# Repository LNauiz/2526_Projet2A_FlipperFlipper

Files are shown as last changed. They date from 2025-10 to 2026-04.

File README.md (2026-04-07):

# 2526_Projet2A_Flipper
Notre objectif est de réaliser un Flipper (ou billard électrique). Notre flipper aurait tous les éléments suivants : les batteurs, les bumpers, un lanceur, un compteur de point et des éclairages (réalisés avec des néopixels), tels que montré sur les dessins suivants : 

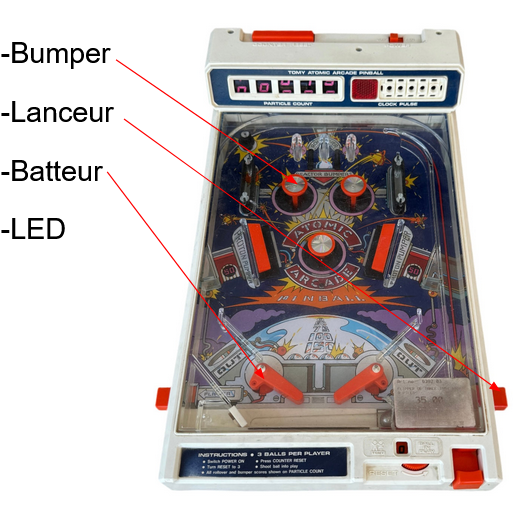
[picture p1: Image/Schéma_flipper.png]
Schéma flipper
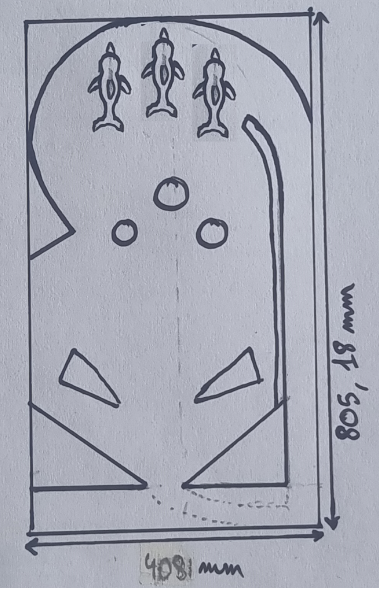
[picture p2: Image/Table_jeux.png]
dessin
 

Afin de marquer des points, le joueur doit soit passer entre les dauphins soit tapper contre les pièces triangulaires ou contre les bumpers.
### Matériel
* Solénoïdes*4 : Heschen Electroaimant solénoïde, HS-1546B, DC24V, 1.5A, course 20 mm, type Push Pull

* Néopixels alimentées à 5 V

* Photodiodes*3

* Détails de la PCB seront donnés dans la partie concernée

### Logiciels utilisés
KiCAD (design PCB), STM32CubeIDE (Software), Onshape (Modélisation 3D)

## Les Bumpers
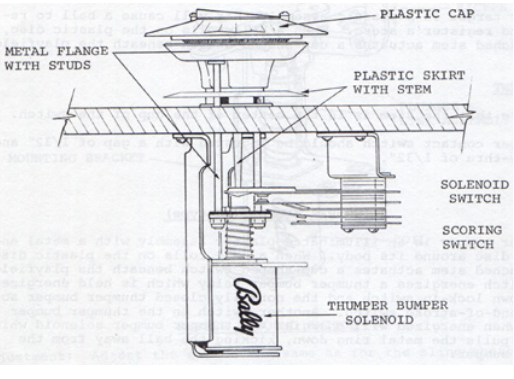
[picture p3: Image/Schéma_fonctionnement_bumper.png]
Schéma fonctionnement bumper


Le fonctionnement du bumper est le suivant : lorsque la balle arrive contre le bumper, elle boucle un circuit entre un anneau proche du circuit ainsi que le cylindre central ce qui va provoquer l'abattement d'une collerette (nommée "metal flange with studs" sur le schéma) repoussant ainsi la balle.
Pour réaliser cet "abattement" on utilise des **solénoïdes** que nous commençons par tester : 
### _Premier test solénoïde_

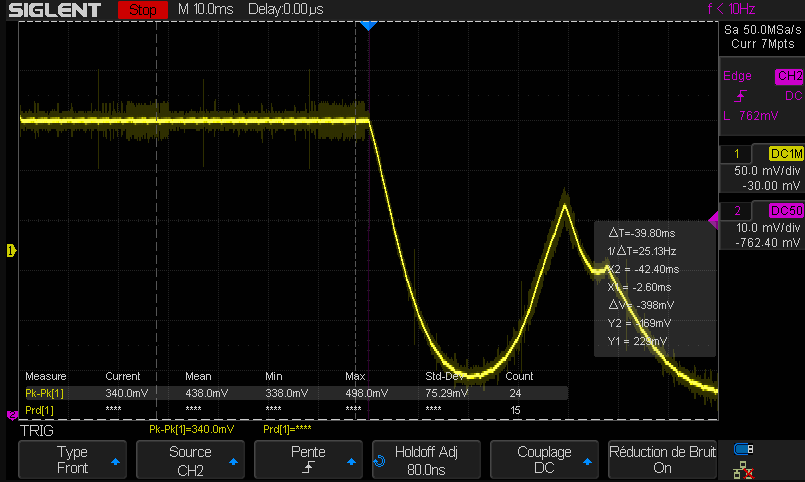
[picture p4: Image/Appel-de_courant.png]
premier test solénoïde


Afin d'utiliser ces solénoïdes pour réaliser des bumpers nous avons besoin d'un support (que nous avons dessiné sur Onshape) :

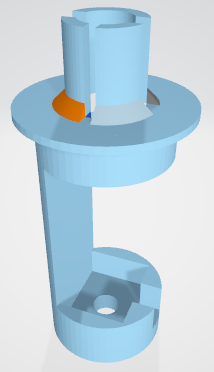
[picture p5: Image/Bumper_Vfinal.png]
Support bumper imprimé


Pour relier la colerette au solénoïde, on utilise des tiges filetés et des écrous nylstop ainsi qu'une pièce imprimé en 3d calée dans le solénoïde.

Afin de détecter si la balle a touché le bumper, nous avons entouré la base et le mât du bumper de scotch cuivré. La balle, en contact avec les deux morceaux de scotch, ferme le cicuit connecté à un GPIO pin de la STM, ce qui permet de commander le solénoïde du bumper.

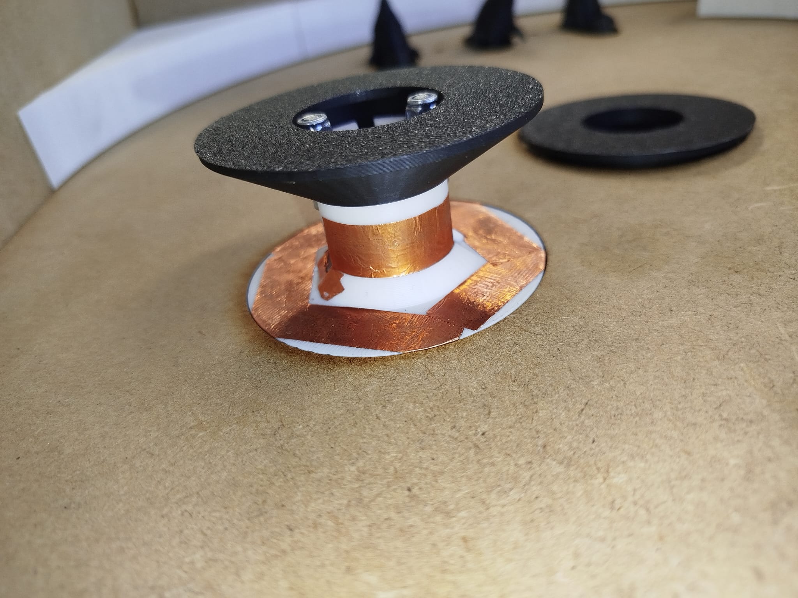
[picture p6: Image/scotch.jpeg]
Scotch

Bottom
## Les Batteurs
Les batteurs sont au nombre de 2 et seront contrôlés par des boutons poussoirs qui activeront d'autres solénoïdes. Ainsi nous avons du réaliser un dispositif afin de pouvoir tranformer la translation produite par le solénoïde en rotation de 60° pour les batteurs. Par Onshape, on modélise les pièces suivantes : 

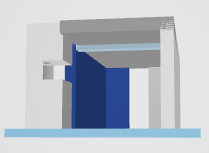
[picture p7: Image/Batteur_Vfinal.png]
Batteur total
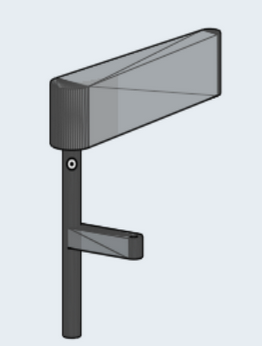
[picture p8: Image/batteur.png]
batteur uniquement
 

Il est nécessaire d'ajouter des écrous nylstops à l'intérieur des pièces pour ne pas que ces derniers se dévissent.\
Malgré cela, on a remarqué que les écrous nylstops avaient une certaine marge de mouvement, ce qui désaxe les batteurs au fil du temps.

## Le Lanceur
La première idée afin de réaliser le lanceur est de réaliser un Coilgun dont le principe est le suivant : 
Nous prenons une balle de 25mm de diamètre que nous voulons faire aller à **6 m/s** lors du lancement ainsi le dimmensionnement de notre Coilgun serait le suivant : 
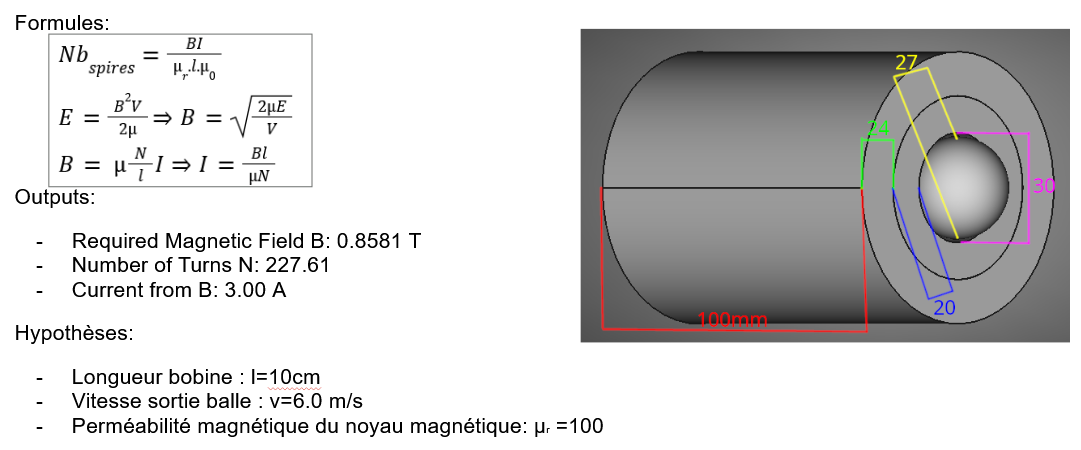
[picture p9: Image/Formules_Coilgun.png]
Calculs Coilgun


Nous avons fini par nous rabattre sur un simple ressort monté sur une tige filetée.

## Les boutons

Après plusieurs tests, nous avons remarqué que les boutons qui étaient, d'après la datasheet, pour du 5V fonctionnaient en 24V. Afin d'avoir un prototype "fonctionnel", nous avons donc simplement branché les batteurs de cette manière: 24V --- Bouton --- Batteur.\
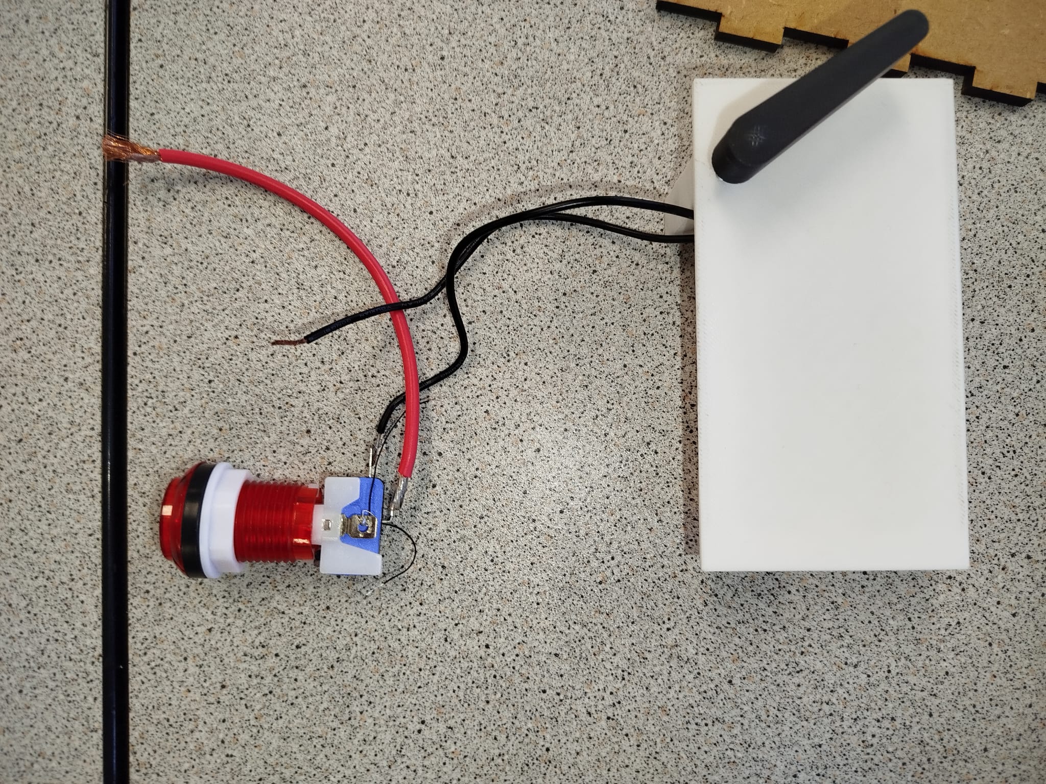
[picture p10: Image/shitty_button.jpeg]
Button


## Le Compteur
Afin d'afficher le score réalisé par le joueur nous devons réaliser un compteur, on utilisera un afficheur 7 segments.\
Pour ce faire nous utiliserons des Néopixels, le code serait réalisé en langage C.\
Voici le support (réalisé sur Onshape) sur lequel nous voulons coller et souder les néopixels : 

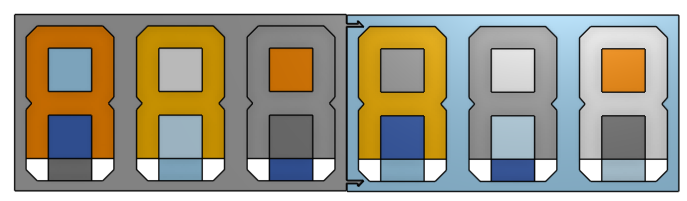
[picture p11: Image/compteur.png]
compteur_imprimé
 

Afin de dissiper la lumière pour ne pas être ébloui par les LED, on peut mettre un difuseur lumineux qui se compose de 1 à 2 couches de PLA.\
Nous avons remarqué que chaque LED doit être séparé par un mur afin de ne pas éclairer les parties des autres (par exemple: le 1 ressemble au 3 sans mur).

## Les Photodiodes
Afin de détecter lorsque la balle passe entre les obstacles ou lorsqu'elle heurte l'obstacle triangulaire du milieu de la table, nous utilisons des photodiodes.
Les premiers tests avec un PCB fait par Monsieur Papazoglou ont été laborieux, on remarque que pour vérifier que ces photodiodes sont bien fonctionnelles nous pouvons lorsqu'elles sont branchées utiliser l'appareil photo de notre téléphone, lorsqu'une lumière violette (le laser) émane de la photodiode, cette dernière est fonctionnelle, si ce n'est pas le cas cela signifie que la photodiode a subi une dégradation irréversible (sûrement du à une alimentation excessive).

## Le PCB
Afin de commander les solénoïdes nous avons réalisé (sur KiCAD) et soudé un premier PCB que voici : 
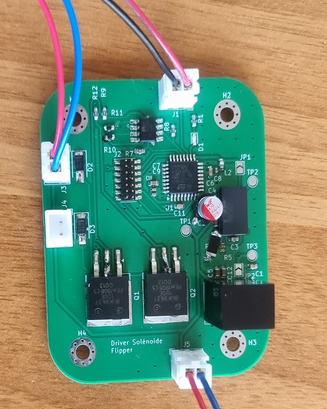
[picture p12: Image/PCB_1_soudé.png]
PCB 1


Lors des soudures nous avons rencontré plusieurs problèmes tels que des empreintes erronées (une résistance R et un condensateur sous-estimés en taille et une patte manquante sur les MOSFETs)
Lors des tests, le Buck de ce premier PCB est fortement monté en température. Nous sommes donc passé au montage suivant (PCB corrigé par Monsieur Papazoglou) :

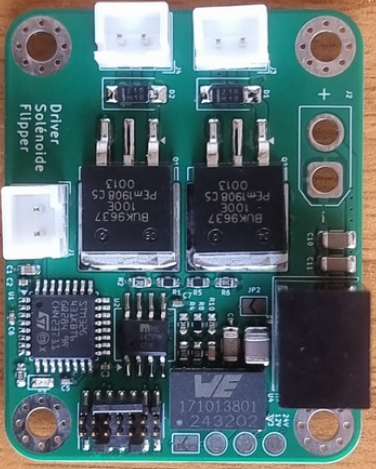
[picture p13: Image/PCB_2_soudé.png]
PCB 2


Lors des test, le Buck de ce PCB est également monté en température. Nous pensons que le problème viendrait d'un court-circuit créé lors de la soudure Pour poursuivre notre projet nous pensons donc changer le buck qui nous cause problème quel que soit le montage par le même type de régulateur à 3 pin que ce celui qui transforme le 24V en 12V. Nous avons construit le PCB avec la possibilité de séparer la partie puissance et la partie commande. Nous avons donc prévu de tester cette dernière lors des prochaines semaines et de commencer à concevoir le PCB final qui commandera l'ensemble du système.

Le PCB final a été réalisé
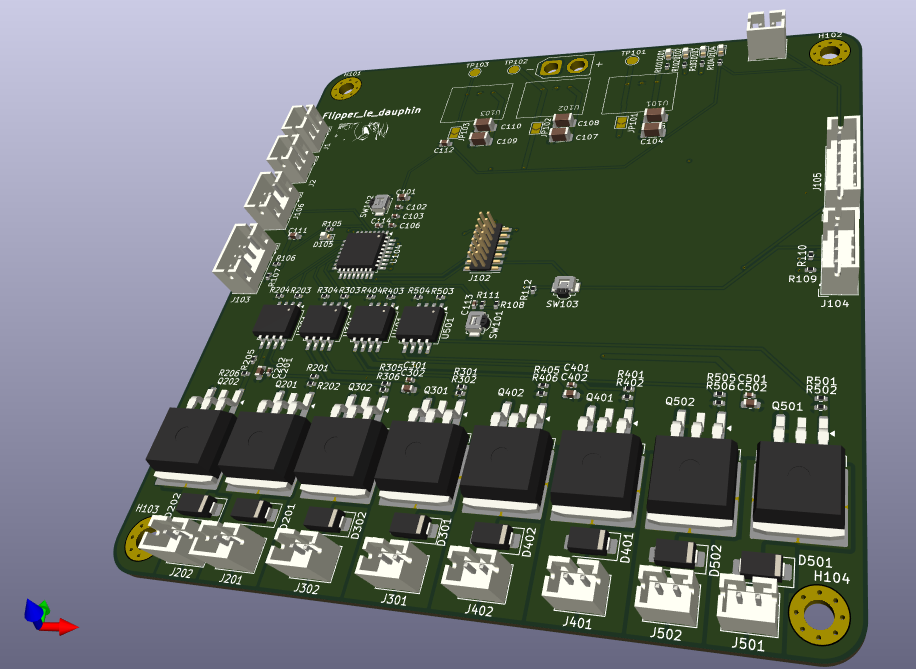
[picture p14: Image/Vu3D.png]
PCB 3


## Software

Voici le schéma fonctionnel de notre système.
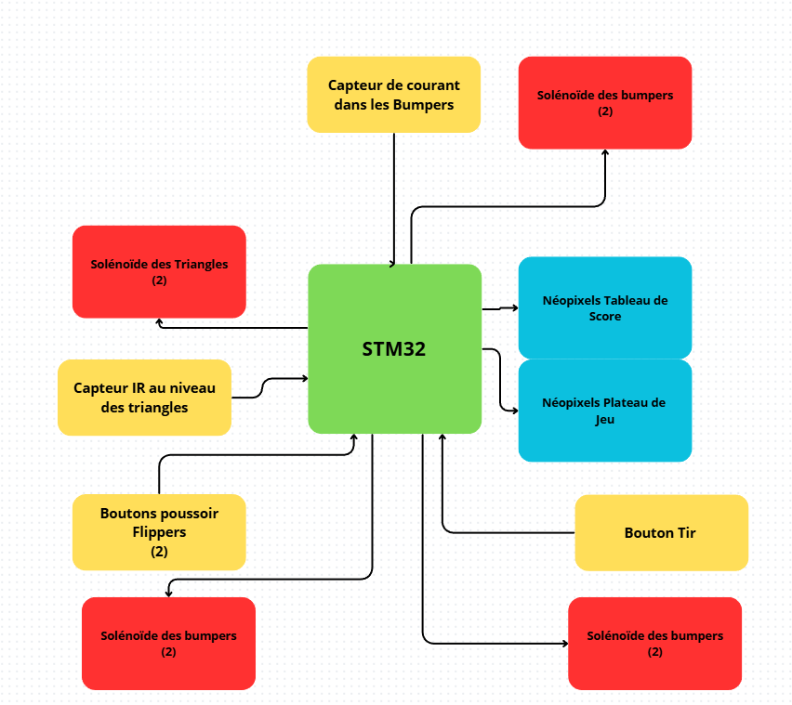
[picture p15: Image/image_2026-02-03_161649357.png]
Schéma


Il nous faut donc jeter un coup d'oeil aux différents capteurs afin de savoir quel information la STM va recevoir. 

## La table de jeux
Afin de réaliser la table de jeux de notre flipper, nous avons décidé de la faire en 2 couches pour y encastrer les différents modules (bumper, batteur...).
Notre première couche est du MDF de 3 mm, gravé afin que nous puissions placer les élèments de la table le mieux possible (rampe de lancement, dauphins...)

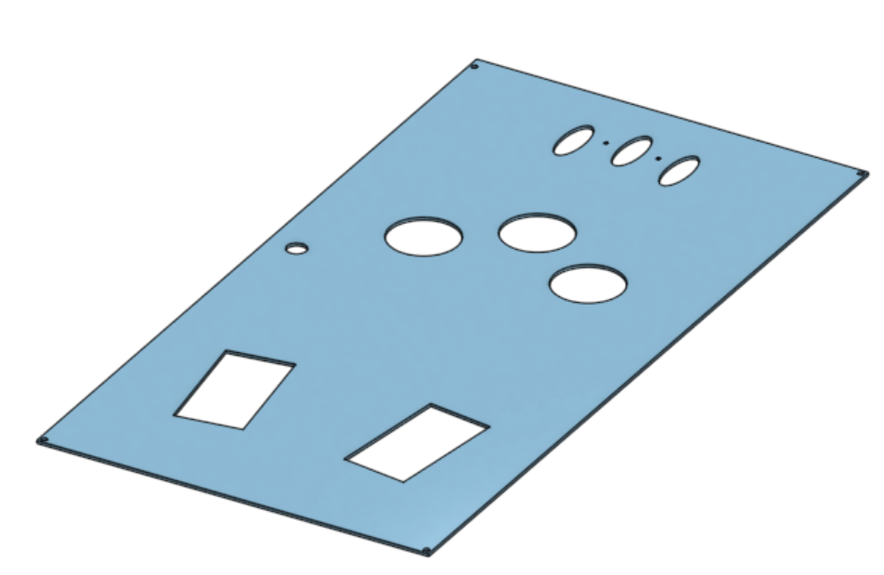
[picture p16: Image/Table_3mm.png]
Table 3mm


Notre deuxième couche est du MDF de 6 mm, des trous d'alignement sont prévus dans les 2 couches pour faciliter la construction

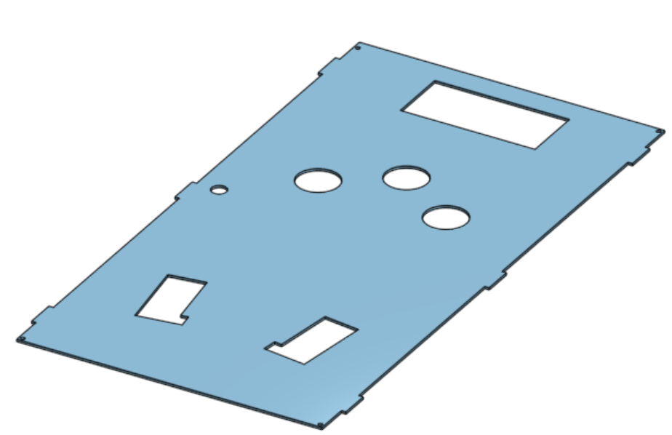
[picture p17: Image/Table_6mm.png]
Table 6mm


Voici le rendu final de la table, une fois assemblée (il faudrait coller les 2 couches de table pour avoir un meilleur rendu)

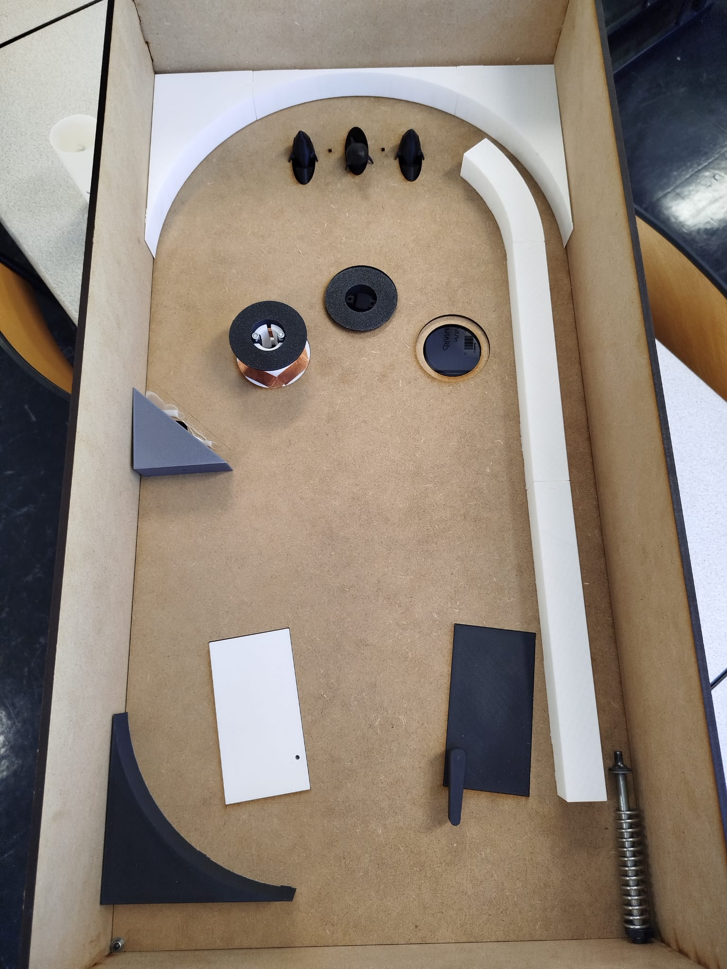
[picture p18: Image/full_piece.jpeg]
Table assemblée


## Le Châssis
Afin d'avoir un support pour notre flipper, nous avons dessiné sur Onshape un châssis en prenant en compte la pente réglementaire pour un Flipper classique qui est de **6,5 °**.

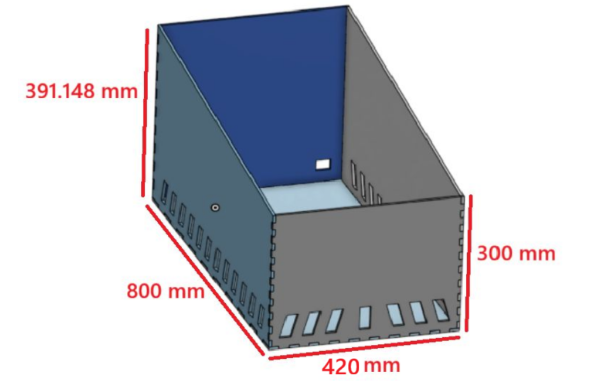
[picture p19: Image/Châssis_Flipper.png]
Châssis Flipper


Le châssis comporte une ouverture afin d'y brancher l'alimentation ainsi que des aérations permettant la ventilation de notre système.
Après avoir réalisé ceci nous sommes entrain de faire la table de jeux qui sera réalisé en 2 couches (afin de pouvoir varier les épaisseurs et de pouvoir y emboîter les supports pour bumper ou batteur)

# Licence
Licence : MIT

Auteurs : Julie Deissard--Decot, Léonard Navizet, Maxime Beltoise, Johann Mansard

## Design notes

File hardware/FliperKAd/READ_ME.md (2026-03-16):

Fonctionalitées attendues:
- Commander 7 Solénoïdes
- Commander 2 Bandes de Néopixels
- Transformer du 24V en 12, 5 et 3.3V
- Récupérer les informations de 3 capteurs IR
- Récupérer le signal de 2 boutons

Liste de courses :
- Régulateur WE en 3.3V
- 3 Solénoïdes
- Billes

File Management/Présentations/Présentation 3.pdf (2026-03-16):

# Projet 2ème année Flipper

## Compteur

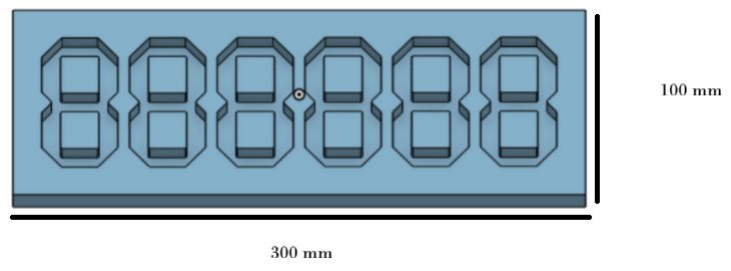
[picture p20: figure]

## Détection des points et compteur

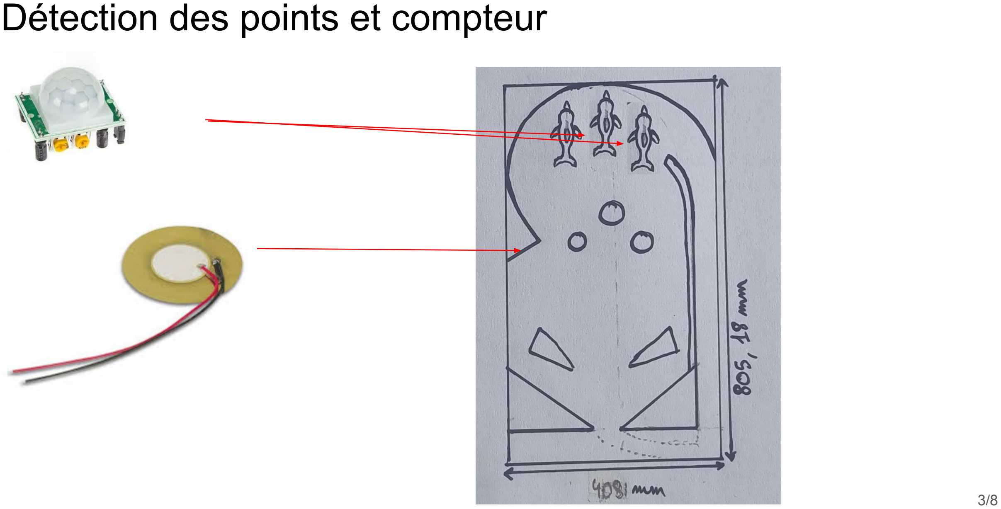
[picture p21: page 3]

PIR sensor

## Coilgun

Formules:

- Nb_Spires = (B*l)/(mu_r*I*mu_0)
- E = B^2 * V / (2 * mu) => B = sqrt(2 * mu * E / V)
- B = mu * (N/l) * I => I = B * l / (mu * N)

Outputs:

- Required Magnetic Field B: 0.8581 T
- Number of Turns N: 227.61
- Current from B: 3.00 A

Hypothèses:

- Longueur bobine : l=10cm
- Vitesse sortie balle : v=6.0 m/s

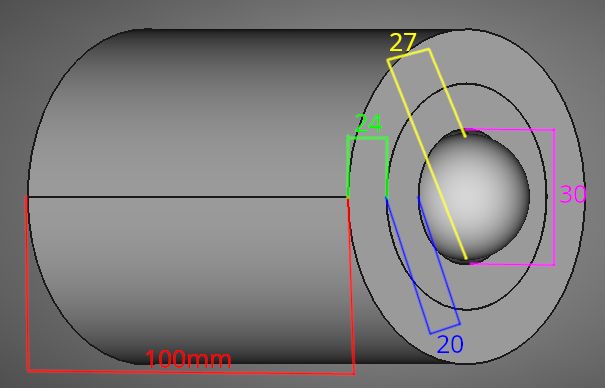
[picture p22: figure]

- Perméabilité magnétique du noyau magnétique: mu_r =100

## Coilgun

Aujourd’hui:

Recherche de fil de cuivre émaillé pour bobine de diamètre 0.8mm, 37m de fil

Recherche du noyau magnétique

Une fois les composants reçus:

Bobinage + Tests

## PCB

PCB arrivé, soudage cet aprem.

Setup de l’alim et programmation de la STM d’ici la semaine prochaine.

Semaine prochaine, test de la carte et début du design du grand PCB/choix des capteurs

## Bumper

Collerette du bumper :

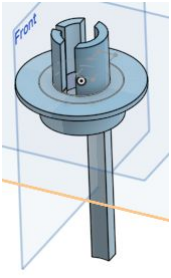
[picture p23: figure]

Support du solénoïde

## Batteur

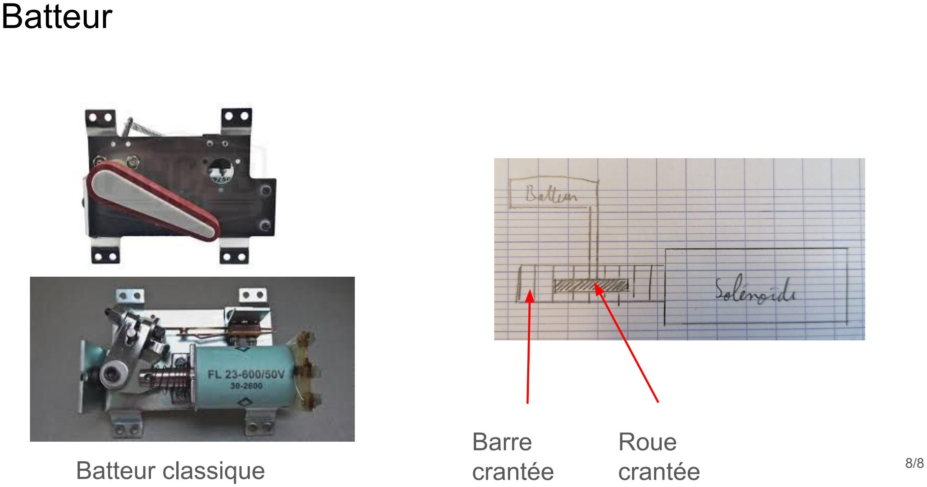
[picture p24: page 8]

8/8 Batteur classique

Barre
crantée

Roue
crantée

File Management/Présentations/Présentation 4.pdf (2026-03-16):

# Projet 2ème année Flipper

## Support de Bumper (Utilisation et amélioration)

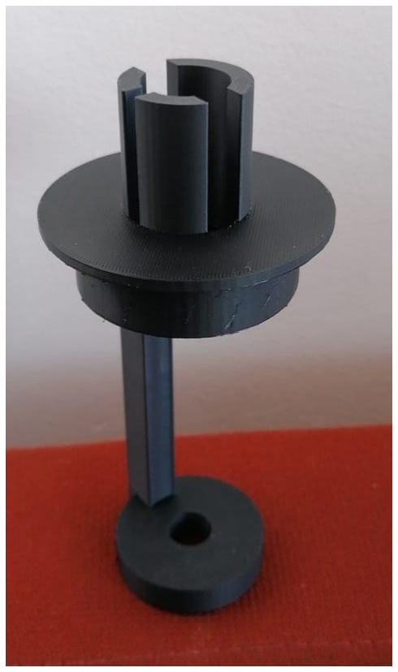
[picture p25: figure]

Il faut tester le solénoïde pour vérifier que l’impression est suffisamment résistante.

Axe d’amélioration :
- ajouter des supports pour bloquer le solénoïde
- renforcer la partie haute en prévision des coups de la boule
- renforcer le support en prévision des coups du solénoïde

## Batteur avec support (Explication)

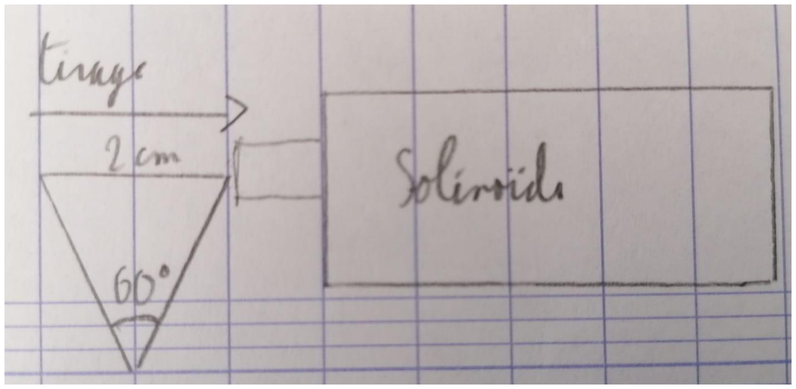
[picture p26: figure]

On a un tirage du solénoïde sur 2cm et on souhaite réaliser une rotation des batteurs de 60°.

Il faut aussi gérer la jonction entre le mouvement de translation du solénoïde et celui du rotation des batteurs. Pour cela on ajoute un petit module supplémentaire.

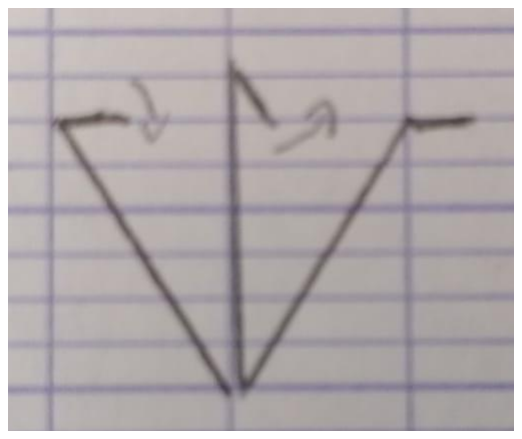
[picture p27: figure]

## Batteur avec support (Conception)

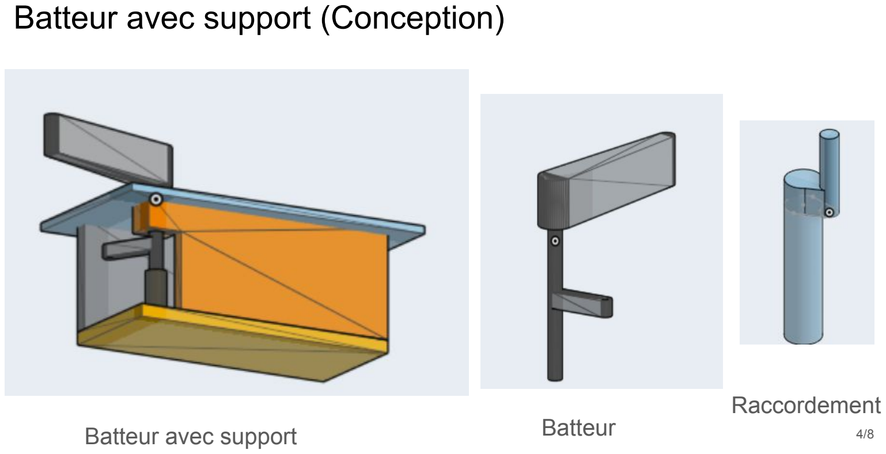
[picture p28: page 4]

Batteur | 4/8 Raccordement
Batteur avec support

## Compteur

- Ajustement de taille pour l’impression
- Code (Johann)
- Manque : Soudure et placement des neopixels

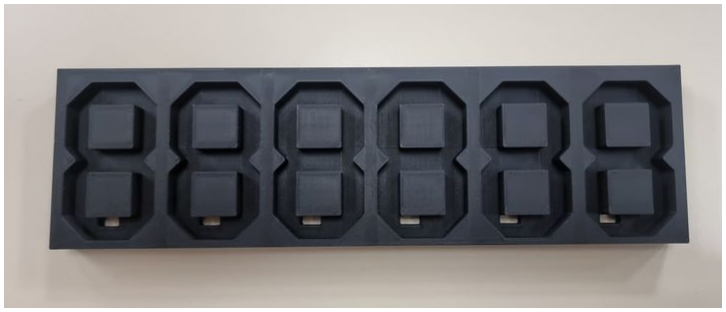
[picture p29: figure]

## Code

Compteur de score fini

Encodage des neopixels à faire

À tester sur STM32

## Soudures et test PCB

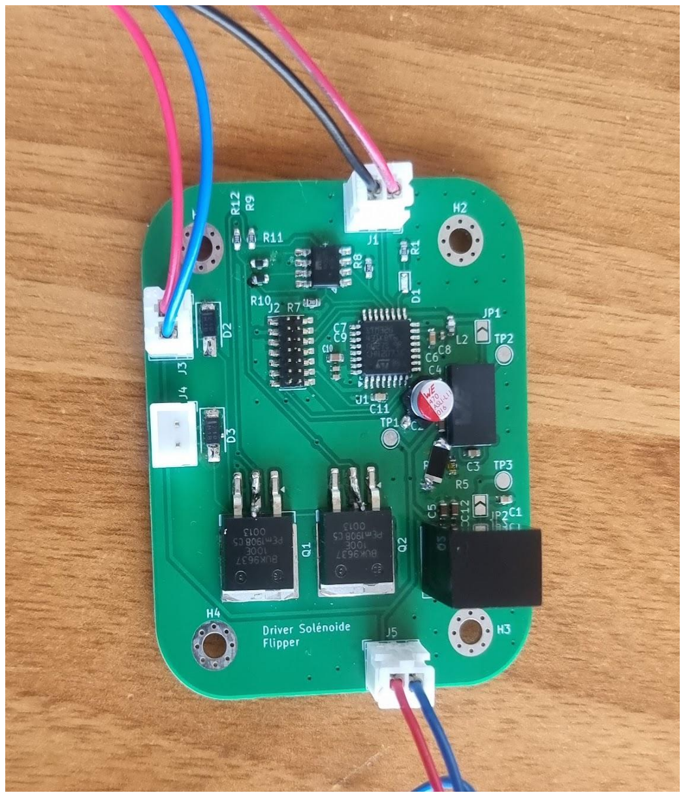
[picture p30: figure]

1er PCB soudé et Testé
-> Problème de CC qui a
cramé un composant causé
par des problèmes
d’empreintes.

## Soudures du 2ème PCB

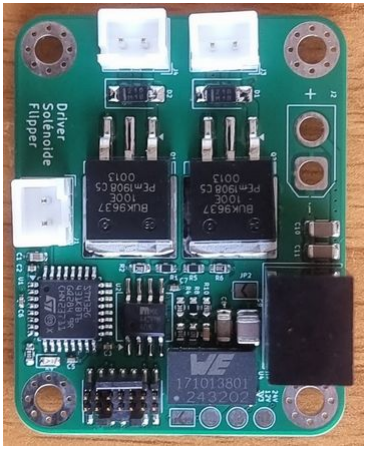
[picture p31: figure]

à faire :
- test 2ème PCB
- Prier pour que les
composants ne crament pas
- Codage
- capteurs pour détecter le passage
- table de jeux (en cours)

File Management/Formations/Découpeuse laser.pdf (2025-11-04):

Découper ou graver les matériaux
Matériaux : bois, plastique (pas tous), plexiglas (prof qui achète)
Image pixelisée (que graver selon niveau de gris -> réglage puissance laser) => pas ouf

ou Vectoriser les images
Pour faire distinction (onShape exporter le sketch pour le truc 3D)
InkScape sinon

1- Importer le fichier dans CorelDraw sur la machine
2- Par défaut tout est graver
Pour découper-> clic trait->propriétés ->contour->Ligne très fine
3- Fichier imprimer (ou ctrl B)
4- Prendre le dessin et le glisser sur le bout de bois
5- réglages dans le bouquin (bientôt affiche avec les réglages simples) demander à quelqu'un du fablab
Côté droit (engrave, vector, 2 réglagles diff)
Puissance de déplacement, Vitesse de déplacement, fréquence
->import material settings (haut droite de l'icône)
6- bouton à l'arrière vers le tube qui va dehors (arrêt urgence, bouton vert)
=> bruit = ok
7- écran sur la laser : joystick, mettre la tête au dessus du matériau -> buse pas laser (truc mou au bout), mettre autofocus
8- Ticket signé!! -> Appuyer sur le bouton play
Et c'est bon
Pas le droit de partir, rester dans la zone
9- ne pas éteindre la laser une fois la pièce finie

En cas de flamme : 1s normal,
si plus appuyer sur pause (il va finir son trait et c'est ok, si vraiment la panique +3s de flamme -> ouvrir un peu la laser)

Précision 0,1 mm => possibilité de mettre proche

Petite verte (pour le métal)

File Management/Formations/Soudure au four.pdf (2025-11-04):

-Caler la carte
-Mettre le stencil (fait avec un fichier gerber) de façon à ne plus voir les couleurs du pcb (voir uniquement le gris)
-Poser la pâte à braser en haut du stencil
-Poser la raclette droite puis la pencher légèrement
-étaler la pâte (plus sur les contours du stencil, uniquement sur la carte) -Poser les composants les plus plats en premier (stm32 en priorité) -Mettre au four

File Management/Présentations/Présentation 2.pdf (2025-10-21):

# Projet 2ème année Flipper

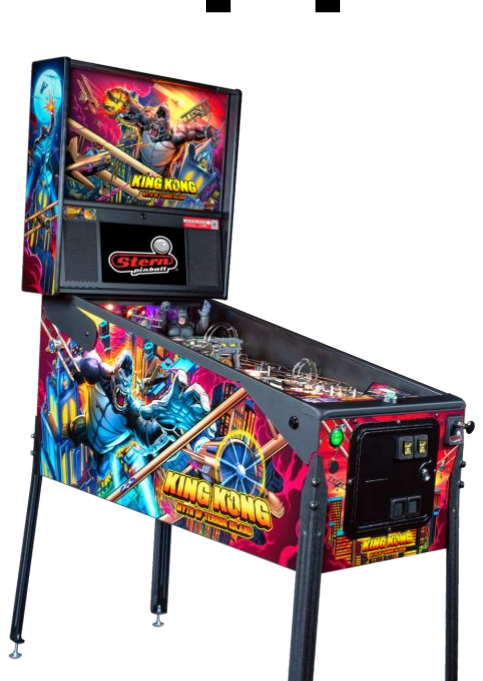
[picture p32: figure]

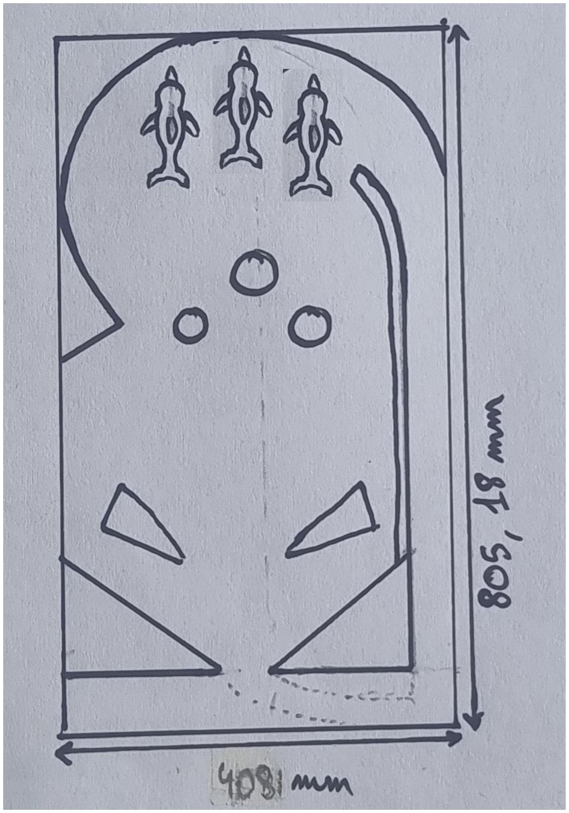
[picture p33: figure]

## La table de jeux

-obstacles statiques

-obstacles dynamiques

-éclairage avec Neopixels

## Châssis

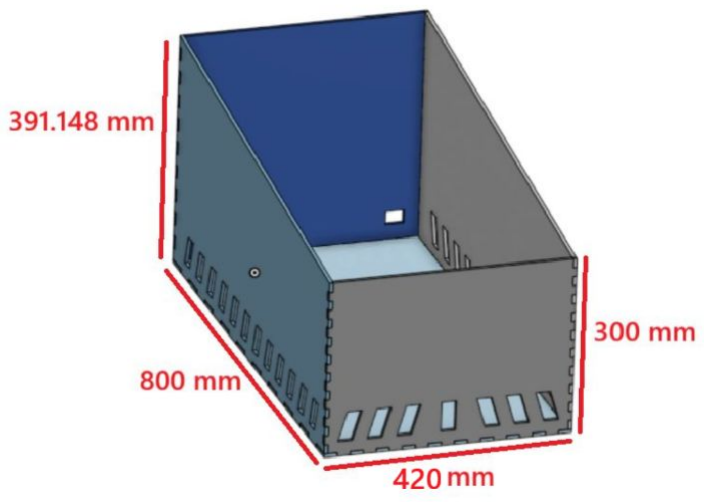
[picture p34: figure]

- pente à 6,5 °
- ventile
- alimentation

## Bumper

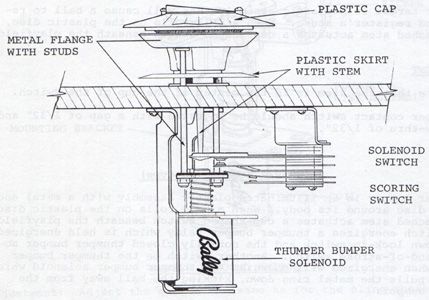
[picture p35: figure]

2 choix possibles pour la détection de la bille :
- capteur de pression/interrupteurs sur un anneau proche du terrain de jeux
- faire en sorte que la bille boucle un circuit entre un anneau proche du terrain de jeux et le cylindre centrale

## PCB(ogoss)

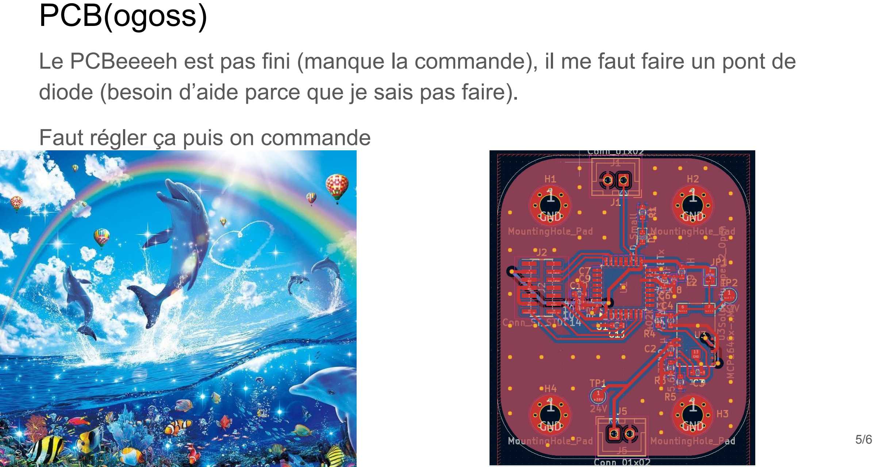
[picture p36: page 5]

Le PCBeeeeh est pas fini (manque la commande), il me faut faire un pont de diode (besoin d’aide parce que je sais pas faire).

Faut régler ça puis on commande

## Coilgun

Dimensionnement :

On veut une vitesse de sortie à 22km/h, balle de 70g

Par conservation de l’énergie, I=131 A

Si on prend un condo à 50mF, R<= 1.90 Ω (donc un

câble)

L=5.8mH (E=LI²/2)

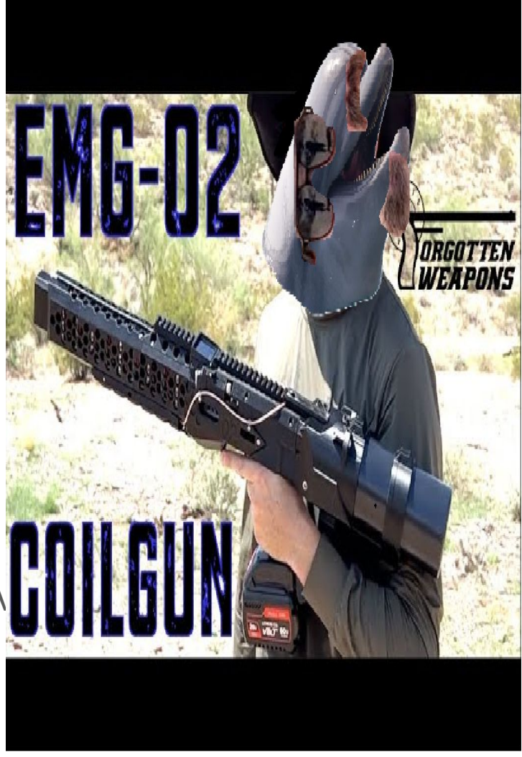
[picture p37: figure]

Suppositions: ηbobine=0.2 ; lbobine=0.01mA ; Vcondo=100V ;; Conservation de l’énergie

temps de décharge : 10ms

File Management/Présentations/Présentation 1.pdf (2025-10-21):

# Projet 2ème année Flipper

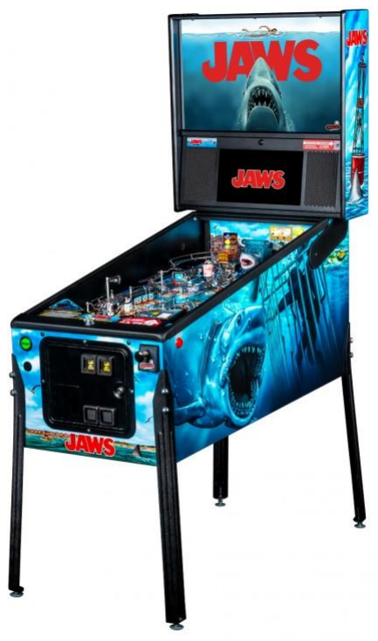
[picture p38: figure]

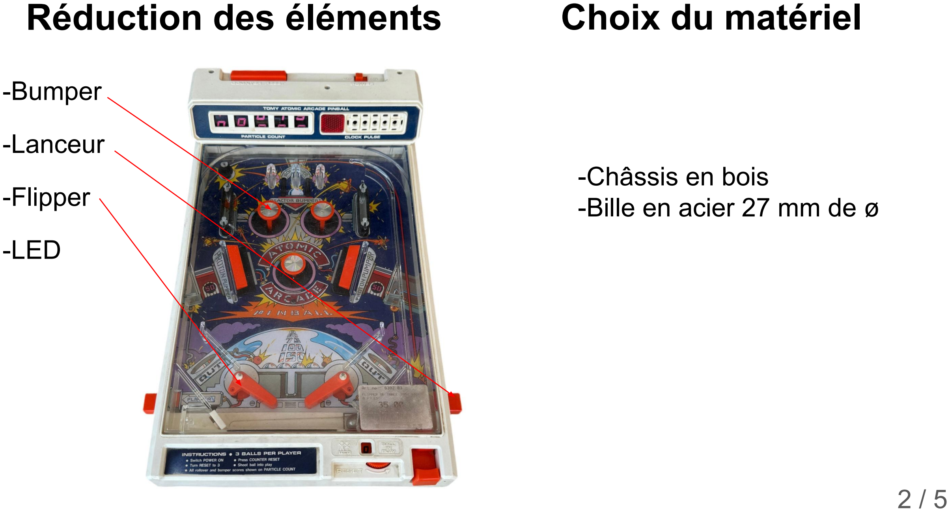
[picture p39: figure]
Réduction des éléments; -Bumper; -Lanceur; -Flipper; -LED; Choix du matériel; -Châssis en bois -Bille en acier 27 mm de ø

## Solénoïde

Avantages : mouvement quasi-instantané avec beaucoup de punch.

Désavantages : - C’est cher (10mm moins de 25 N à 14,99€)

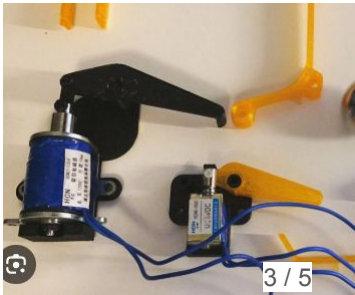
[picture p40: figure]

- Eplucher de la doc

On va tenter de l’utiliser pour les bumpers et les

flippers

On doit faire un PCB pour vérifier leur fonctionnement

## Coilgun / PCB

Lanceur fait avec un CoilGun | PCB
| -relie tous les éléments -tableau des scores -transformateur -vérification du fonctionnement des

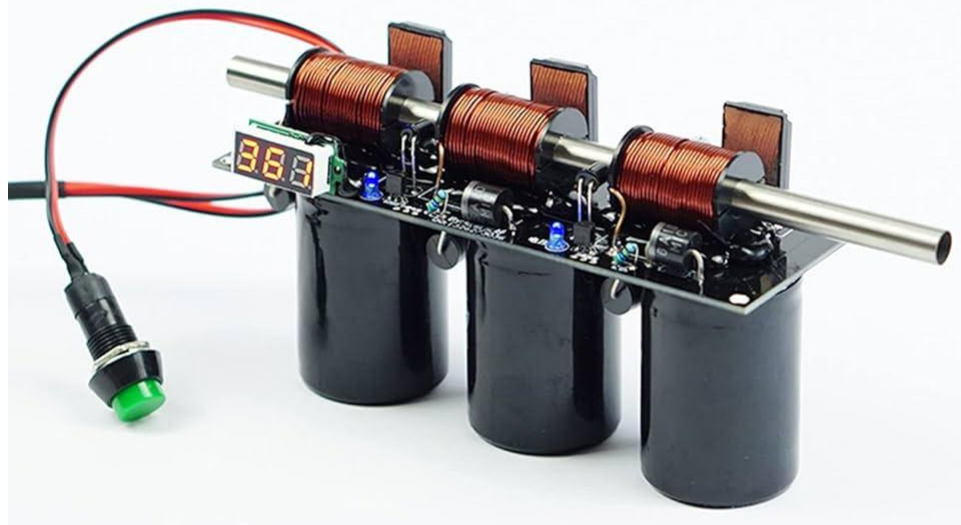
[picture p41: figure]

solénoïdes

## GANTT

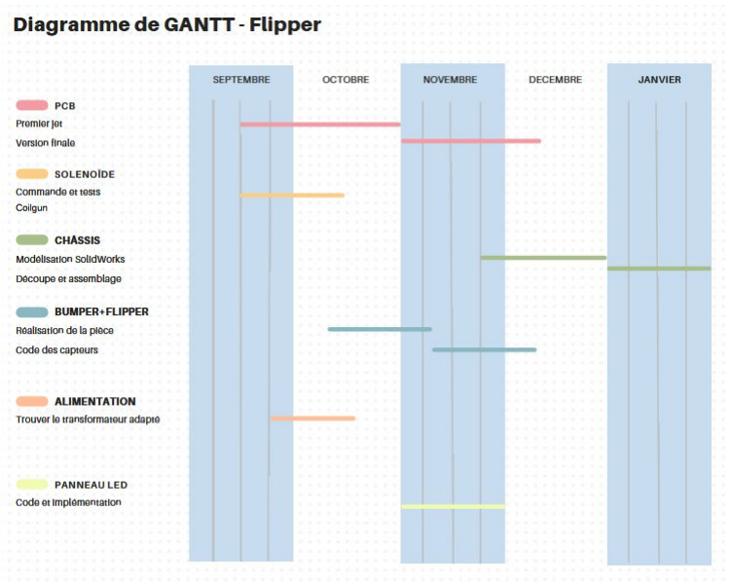
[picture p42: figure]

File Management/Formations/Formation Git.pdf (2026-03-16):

## ATHENA - Formation GIT Débutant

Alain Piallat

13 janvier 2026

Alain Piallat | Formation GIT(1/57) | 13 janvier 2026

## Sommaire

Introduction
Installation et configuration Principe de fonctionnement Commandes de base
Bonnes pratiques
Commandes avancées : Les
branches

Commandes avancées : Autres Workflow collaboratif
Erreurs courantes et solutions Outils et ressources
Conseils
Conclusion

Cette formation couvre à la fois les notions fondamentales et des thèmes avancés. Pour faciliter l’apprentissage, les diapositives présentant des concepts élémentaires - nécessaires pour une utilisation basique de Git -seront signalées par le symbole ♣ dans leur titre.

Alain Piallat | Formation GIT(2/57) | 13 janvier 2026

## Qu’est-ce que GIT ?

- Créé par Linus Torvalds en 2005 pour le développement du noyau Linux.
- GIT est un système de contrôle de version.
- Il permet de suivre les modifications apportées aux fichiers et de collaborer avec d’autres utilisateurs.
- GIT est distribué, chaque utilisateur possède une copie complète du dépôt.
- Utilisé principalement pour le code source, mais peut gérer tout type de fichier.
Alain Piallat | Formation GIT(3/57) | 13 janvier 2026

## Git vs GitHub/GitLab

Git :
- Système de contrôle de version
- Fonctionne en local et en ligne de commande
- Gère les versions, branches, fusions, etc.

GitHub / GitLab :
- Plateformes d’hébergement de dépôts Git
- Fournissent une interface web
- Facilitent la collaboration et le partage de code
- Offrent des fonctionnalités supplémentaires (pull requests, wikis, etc.)

Git est l’outil, GitHub est le service en ligne basé sur Git.

Alain Piallat | Formation GIT(4/57) | 13 janvier 2026

## Installation ♣

Linux :
- Ubuntu/Debian : sudo apt install git
- Fedora : sudo dnf install git

Windows et macOS :
- Aller sur https://git-scm.com/install/
- Suivre les instructions pour votre OS

Vérifier l’installation :

1 | user@machine :~ $ git -- version
2 | git version 2. x . x
Alain Piallat | Formation GIT(5/57) | 13 janvier 2026

## Configuration initiale ♣

Configurer votre identité (obligatoire) :

1 | git config -- global user . name " Votre Nom "
2 | git config -- global user . email " email@example . com "

Vérifier la configuration :

1 | user@machine :~ $ git config -- list
2 | user . name = Votre Nom
3 | user . email = email@example . com

Il existe trois niveaux de configuration : Pour tout les utilisateurs (--system), pour l’utilisateur courant (--global), pour le dépôt courant (sans option ou --local).

Alain Piallat | Formation GIT(6/57) | 13 janvier 2026

## Autres options de configuration courantes

Configurer l’éditeur par défaut :

1 git config -- global core . editor < commande - editeur >

Exemples : code –wait (VSCode), nano, vim
Gérer les fins de ligne :

1 git config -- global core . autocrlf true

Permet d’éviter les problèmes de fin de ligne entre Windows et Linux/macOS.
Il existe de nombreuses autres options qui ne seront pas abordées ici. https://git-scm.com/book/fr/v2/Personnalisation-de-Git-Configuration-de-Git (https://git-scm.com/book/fr/v2/Personnalisation-de-Git-Configuration-de-Git)
Alain Piallat | Formation GIT(7/57) | 13 janvier 2026

## HTTPS vs SSH ♣

Pour interagir avec des dépôts git distants (push, pull), deux méthodes principales existent HTTPS et SSH.
HTTPS :
- Simple à configurer
- Nécessite de saisir vos identifiants à chaque interaction
- Moins sécurisé pour les opérations fréquentes

SSH (recommandé) :
- Plus sécurisé et pratique
- Utilise des clés SSH pour l’authentification
- Nécessite une configuration initiale (mais plus rien par la suite)
Alain Piallat | Formation GIT(8/57) | 13 janvier 2026

## Configuration SSH - Génération de clés ♣

Étape 1 : Générer une paire de clés SSH

1 ssh - keygen -t ed25519 -C " votre . email@ensea . fr "

- Appuyez sur Entrée pour accepter l’emplacement par défaut
- Optionnel : entrez une passphrase pour plus de sécurité Étape 2 : Démarrer l’agent SSH
1 | # Linux
2 | eval " $ ( ssh - agent -s ) "
3 | ssh - add ~/. ssh / id_ed25519

4
5 | # Windows ( PowerShell )
6 | Get - Service - Name ssh - agent | Set - Service - StartupType
| Manual # Necessite les droits admin
7 | Start - Service ssh - agent
8 | ssh - add ~\. ssh \ id_ed25519
Alain Piallat | Formation GIT(9/57) | 13 janvier 2026

## Configuration SSH - Ajout sur GitHub ♣

Étape 3 : Copier la clé publique

1 | # Linux
2 | cat ~/. ssh / id_ed25519 . pub

3
4 | # Windows ( PowerShell )
5 | Get - Content ~\. ssh \ id_ed25519 . pub

Étape 4 : Ajouter la clé sur GitHub/GitLab

1. Aller dans Settings > SSH and GPG keys
2. Cliquer sur "New SSH key"
3. Coller votre clé publique
4. Donner un titre descriptif (ex : "PC personnel")
5. Cliquer sur "Add SSH key"
Tester la connexion :
1 | ssh -T git@github . com
Alain Piallat | Formation GIT(10/57) | 13 janvier 2026

## Plomberie vs Porcelaine

Plomberie (plumbing) :
- Commandes basses niveaux
- Manipulation directe des objets Git
- Exemples : git hash-object, git cat-file

Porcelaine (porcelain) :
- Commandes haut niveau
- Interfaces conviviales pour les utilisateurs
- Exemples : git add, git commit, git push

Nous nous concentrerons sur la porcelaine dans cette formation.

Alain Piallat | Formation GIT(11/57) | 13 janvier 2026

## Architecture de Git

Principes clés :
- Chaque dépôt est une base de données complète
- Les modifications sont enregistrées via des commits
- Le staging permet de préparer les changements avant le commit

Trois zones principales :
1. Working Directory : vos fichiers de travail
2. Staging Area (Index) : zone de préparation
3. Repository (.git) : historique des versions

Working Dir

git add

−−−−→ Staging git commit
−−−−−−→ Repository
Alain Piallat | Formation GIT(12/57) | 13 janvier 2026

## Local vs Remote

Dépôt local :
- Sur votre machine
- Travail hors ligne possible
- Commits locaux rapides

Dépôt distant (remote) :
- Hébergé sur GitHub/GitLab/etc.
- Partage avec l’équipe
- Sauvegarde externe
Alain Piallat | Formation GIT(13/57) | 13 janvier 2026

## Pricipales commandes essentielles à maîtriser ♣

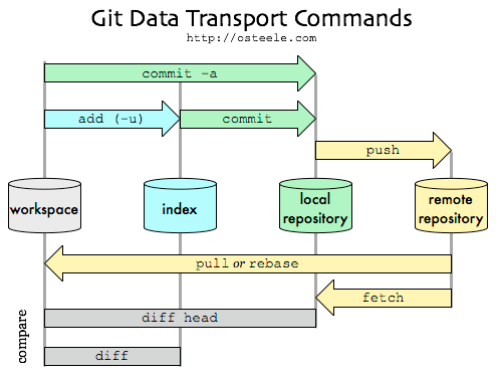
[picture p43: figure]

Alain Piallat | Formation GIT(14/57) | 13 janvier 2026

## git init / git clone ♣

Créer un nouveau dépôt :

1 git init [ nom - du - dossier ]

Cloner un dépôt existant :

1 | git clone https :// github . com / user / repo . git [ nom ]
2 | git clone git@github . com : user / repo . git [ nom ]

Le clonage crée automatiquement un dépôt local avec un remote nommé "origin"

Attention : l’url est modifiée avec ssh

Alain Piallat | Formation GIT(15/57) | 13 janvier 2026

## git add ♣

Ajouter des fichiers au staging :

1 | git add fichier . txt | # Un fichier specifique
2 | git add dossier / | # Tout un dossier
3 | git add . | # Tous les fichiers modifies
4 | git add *. py | # Tous les fichiers .py

Le staging permet de :
- Choisir quels changements inclure dans le commit
- Organiser ses commits de manière logique
- Vérifier avant de valider définitivement
Alain Piallat | Formation GIT(16/57) | 13 janvier 2026

## git commit ♣

Enregistrer les modifications :

1 git commit -m " Message descriptif "

Commit avec éditeur pour message long :

1 git commit

Ajouter et commiter en une fois :

1 git commit -a # Seulement fichiers suivis

Chaque commit crée un point de sauvegarde unique

Alain Piallat | Formation GIT(17/57) | 13 janvier 2026

## git log

Visualiser l’historique :

1 | git log | # Historique complet
2 | git log -- oneline | # Version condensee
3 | git log -- graph | # Avec representation
| graphique
4 | git log -- all -- decorate # Toutes les branches

Affiche pour chaque commit :
- Hash unique (identifiant)
- Auteur et date
- Message de commit

--oneline et --graph peuvent être combinés, cela donne une vue d’ensemble claire de l’historique (similaire à celle fournie par des outils graphiques).
git log ouvre vim par défaut pour la navigation. Taper ’q’ pour quitter.
Alain Piallat | Formation GIT(18/57) | 13 janvier 2026

## git diff

Voir les modifications :

1 | git diff | # Modifications non stagees
2 | git diff -- staged | # Modifications stagees
3 | git diff HEAD | # Toutes les modifications
4 | git diff commit1 commit2 # Entre deux commits

Utile pour :
- Vérifier ce qui a changé avant de commiter
- Comprendre les différences entre versions
- Relire son code avant validation
Alain Piallat | Formation GIT(19/57) | 13 janvier 2026

## git rm et git mv

Supprimer un fichier du dépôt :

1 | git rm fichier . txt | # Supprime et stage
2 | git rm -- cached fichier . txt | # Retire du suivi Git
| uniquement

Renommer ou déplacer un fichier :

1 | git mv ancien . txt nouveau . txt
2 | git mv fichier . txt dossier /

Ces commandes stagent automatiquement les changements

Alain Piallat | Formation GIT(20/57) | 13 janvier 2026

## git status

Voir l’état du dépôt :

1 git status

Affiche :
- La branche courante
- Les fichiers modifiés
- Les fichiers en staging
- Les fichiers non suivis

Commande la plus utilisée ! À utiliser sans modération.

Alain Piallat | Formation GIT(21/57) | 13 janvier 2026

## git status example

1 | On branch main
2 | Changes to be committed :
3 | ( use " git restore -- staged <file >... " to unstage )
4 | modified : | fichier1 . txt
5 | new file : | fichier2 . txt
6 | Changes not staged for commit :
7 | ( use " git add < file >... " to update what will be
| committed )
8 | ( use " git restore < file >... " to discard changes in
working directory )
9 | modified : | fichier3 . txt
10 | Untracked files :
11 | ( use " git add < file >... " to include in what will be
| committed )
12 | fichier4 . txt
Alain Piallat | Formation GIT(22/57) | 13 janvier 2026

## git push ♣

Envoyer les commits vers le dépôt distant :

1 | git push | # Push la branche
| courante
2 | git push < remote > < branch > | # Push vers la branche de
| remote

Important :
- Partage vos modifications avec l’équipe
- Nécessite des droits d’écriture
- Sauvegarde externe de votre travail
Alain Piallat | Formation GIT(23/57) | 13 janvier 2026

## git pull ♣

Récupérer les modifications distantes :

1 | git pull | # Pull la branche
| courante
2 | git pull origin main | # Pull depuis main sur
| origin

Git pull = git fetch + git merge
- Récupère les changements distants
- Fusionne avec votre branche locale dans votre working directory
- Peut provoquer des conflits à résoudre manuellement

Toujours pull avant de commencer à travailler !

Alain Piallat | Formation GIT(24/57) | 13 janvier 2026

## Quand et comment commiter

Principe d’atomicité :
- Un commit = une modification logique
- Pas trop gros (difficile à relire)
- Pas trop petit (historique pollué)

Fréquence :
- Après chaque fonctionnalité complète
- Avant de changer de tâche
Alain Piallat | Formation GIT(25/57) | 13 janvier 2026

## Syntaxe des messages de commit

Format standard :

1 Type : Sujet court (50 caracteres max )

2
3 | Description optionnelle plus detaillee expliquant
4 | le pourquoi et le comment du changement .

Types courants :
- feat: nouvelle fonctionnalité
- fix: correction de bug
- docs: documentation
Alain Piallat | Formation GIT(26/57) | 13 janvier 2026

## Exemples de bons messages

Bons exemples :

1 | feat : Ajoute l ’ authentification par OAuth
2 | fix : Corrige le bug de connexion sur Safari
3 | docs : Met a jour le README avec instructions Docker

Mauvais exemples :

1 | update | # Trop vague
2 | fixed stuff | # Pas assez descriptif
3 | azertyuiop | # Inutile
4 | WIP | # Work In Progress , a eviter
Alain Piallat | Formation GIT(27/57) | 13 janvier 2026

## Le fichier .gitignore

Que faut-il exclure du versioning ?
- Fichiers générés (build, compiled)
- Dépendances (node_modules/, venv/)
- Fichiers de configuration locale
- Fichiers sensibles (clés API, mots de passe)
- Fichiers temporaires, logs
- Fichiers IDE (.vscode/, .idea/)

Ressource : github.com/github/gitignore

Alain Piallat | Formation GIT(28/57) | 13 janvier 2026

## Exemple de .gitignore

1 | # Fichiers de compilation
2 | *. o
3 | *. s

4
5 | # Fichiers IDE
6 | . vscode /

7
8 | # Fichiers sensibles
9 | . env
10 | config . local . json
Alain Piallat | Formation GIT(29/57) | 13 janvier 2026

## README.md

Le README est la vitrine de votre projet Contenu typique :
- Titre et description du projet
- Instructions d’installation
- Exemples d’utilisation
- Technologies utilisées
- Comment contribuer
- Licence
- Contact/auteurs

Privilégier le format Markdown

Alain Piallat | Formation GIT(30/57) | 13 janvier 2026

## Choisir une licence

Pourquoi une licence ?
- Définit les droits d’utilisation
- Protège votre travail
- Clarifie les conditions de partage

Licences courantes :
- MIT : très permissive, usage libre
- GPL : copyleft, modifications open-source
- Apache 2.0 : permissive avec protection brevets
- CC BY : pour contenu non-logiciel

Ressource : choosealicense.com

Alain Piallat | Formation GIT(31/57) | 13 janvier 2026

## Principe et utilité des branches

Une branche = une ligne de développement parallèle Cas d’usage :
- Développer une nouvelle fonctionnalité
- Corriger un bug sans perturber le code principal
- Expérimenter sans risque
- Travailler à plusieurs sans conflit
Alain Piallat | Formation GIT(32/57) | 13 janvier 2026

## git branch ♣

Lister les branches :

1 | git branch | # Branches locales
2 | git branch -a | # Toutes les branches (+ remotes )
3 | git branch -v | # Avec dernier commit

Créer une branche :

1 git branch nom - branche

Supprimer une branche :

1 | git branch -d nom - branche | # Si fusionnee
2 | git branch -D nom - branche | # Force la suppression
Alain Piallat | Formation GIT(33/57) | 13 janvier 2026

## git checkout / git switch

Changer de branche (ancienne méthode) :

1 | git checkout nom - branche
2 | git checkout -b nouvelle - branche | # Creer et basculer

Nouvelle syntaxe (Git 2.23+) :

1 | git switch nom - branche
2 | git switch -c nouvelle - branche | # Creer et basculer

git switch est plus clair et recommandé

Alain Piallat | Formation GIT(34/57) | 13 janvier 2026

## git merge ♣

Fusionner une branche dans la branche courante :

1 | git switch main
2 | git merge feature - xyz

Types de merge :
- Fast-forward : simple avance du pointeur
- Merge commit : crée un commit de fusion (en cas de conflit)
- Squash merge : regroupe tous les commits en un seul
1 | git merge -- squash feature - xyz
Alain Piallat | Formation GIT(35/57) | 13 janvier 2026

## Résolution de conflits

Un conflit survient quand :
- Deux branches modifient les mêmes lignes
- Git ne peut pas fusionner automatiquement

Résolution :
1. Git marque les conflits dans les fichiers
2. Ouvrir les fichiers et choisir la bonne version
3. Supprimer les marqueurs de conflit
4. git add les fichiers résolus
5. git commit pour finaliser le merge

Les IDE modernes facilitent grandement cette étape

Alain Piallat | Formation GIT(36/57) | 13 janvier 2026

## Marqueurs de conflit

Exemple de conflit :

1 | <<<<<<< HEAD
2 | Code de votre branche courante
3 | =======
4 | Code de la branche a fusionner
5 | >>>>>>> feature - xyz

Après résolution :

1 | Code final que vous avez choisi
Alain Piallat | Formation GIT(37/57) | 13 janvier 2026

## git rebase : réorganiser l’historique

Rebase applique vos commits sur une autre base :

1 | git switch feature
2 | git rebase main

Différence avec merge :
- Merge : conserve l’historique complet
- Rebase : crée un historique linéaire plus propre

Attention : ne jamais rebaser des commits déjà pushés !

Alain Piallat | Formation GIT(38/57) | 13 janvier 2026

## Commandes avancés

Dans cette section, nous allons abordées des commandes avancées pouvant causer des modifications importantes dans votre dépôt voir la perte de données si elles sont mal utilisées.

# Renseignez-vous bien avant de

les utiliser.

Alain Piallat | Formation GIT(39/57) | 13 janvier 2026

## git fetch : récupérer sans fusionner

Récupérer les modifications distantes sans fusion :

1 | git fetch | # Recupere tous les remotes
2 | git fetch origin main | # Recupere main depuis origin

Comparer avec votre branche locale :

1 git diff main origin / main

Utile pour voir les changements avant de fusionner

Alain Piallat | Formation GIT(40/57) | 13 janvier 2026

## git stash : sauvegarder temporairement

Mettre de côté des modifications :

1 | git stash | # Sauvegarde et nettoie
2 | git stash save " Message " | # Avec description

Récupérer les modifications :

1 | git stash list | # Lister les stashs
2 | git stash apply [ stash@ { index }] # Applique le dernier
3 | git stash pop | # Applique et supprime
4 | git stash drop [ stash@ { index }] | # Supprime un stash

Utile pour : changer de branche rapidement sans commiter

Alain Piallat | Formation GIT(41/57) | 13 janvier 2026

## git reset : annuler des modifications

Cette commande permet de réécrire l’historique en annulant des commits. Trois modes de reset :

1 | git reset -- soft HEAD ~1 | # Garde staging et working
2 | git reset -- mixed HEAD ~1 | # Garde working ( defaut )
3 | git reset -- hard HEAD ~1 | # Supprime tout

Retirer du staging :

1 git reset fichier . txt

HEAD désigne le commit courant. le 1 signifie "le parent", 2 le grand-parent, etc.

Attention : –hard est destructif !

Alain Piallat | Formation GIT(42/57) | 13 janvier 2026

## git revert : annuler proprement

Créer un commit qui annule un commit précédent :

1 | git revert abc123 | # Annule le commit abc123
2 | git revert HEAD | # Annule le dernier commit

Différence avec reset :
- reset : réécrit l’historique (fait disparaître des commits)
- revert : ajoute un nouveau commit (plus transparent)

Préférer revert pour des commits déjà pushés

Alain Piallat | Formation GIT(43/57) | 13 janvier 2026

## git cherry-pick

Appliquer un commit spécifique sur la branche courante :

1 git cherry - pick abc123

Utile pour :
- Récupérer un fix d’une autre branche
- Appliquer sélectivement des commits
- Éviter un merge complet
Alain Piallat | Formation GIT(44/57) | 13 janvier 2026

## Workflow collaboratif

Dans cette section, nous allons sortir du cadre de git pour aborder les dépots collaboratifs hébergés sur des plateformes comme GitHub ou GitLab.

Alain Piallat | Formation GIT(45/57) | 13 janvier 2026

## Fork : copier un projet

Le fork crée une copie indépendante d’un dépôt. Il permet de travailler sur un projet sans avoir besoins d’être ajouté en tant que collaborateur.
Processus :
1. Fork sur GitHub/GitLab (bouton "Fork")
2. Clone de votre fork en local
3. Modifications et commits
4. Push vers votre fork
5. Pull request vers le projet original
Alain Piallat | Formation GIT(46/57) | 13 janvier 2026

## Pull Requests / Merge Requests

Pull Request ou PR (GitHub) / Merge Request (GitLab) : demande de fusionner vos modifications dans le dépôt principal. Elle permet :
- Revue de code avant intégration
- Discussion sur les modifications
- Traçabilité des changements
- Validation par l’équipe

Standard pour le développement collaboratif moderne

Alain Piallat | Formation GIT(47/57) | 13 janvier 2026

## Revue de code

La revue de code consiste à examiner les modifications proposées dans une pull request et à fournir des retours constructifs. Elle peut inclure :
- Vérification de la qualité du code
- Suggestions d’amélioration
- Détection de bugs potentiels
- Validation des normes de codage
- Tests et vérifications
Alain Piallat | Formation GIT(48/57) | 13 janvier 2026

## Erreurs courantes

Dans cette section, nous allons aborder quelques erreurs courantes rencontrées lors de l’utilisation de Git ainsi que leurs solutions.

Alain Piallat | Formation GIT(49/57) | 13 janvier 2026

## Commit sur la mauvaise branche

Problème : vous avez commité sur main au lieu de votre branche Solution (commit non pushé) :

1 | # Annule le commit (en gardant les changements )
2 | git reset -- soft HEAD ~1
3 | git switch -c feature | # Cree la bonne branche
4 | git commit -m " Message " | # Recommite

Ou avec cherry-pick :

1 | git switch -c feature | # Nouvelle branche
2 | git cherry - pick main | # Copie le commit
3 | git switch main
4 | git reset -- hard HEAD ~1 | # Supprime sur main
Alain Piallat | Formation GIT(50/57) | 13 janvier 2026

## Conflit de merge bloquant

Vous êtes bloqué en plein merge avec des conflits Options :

1 | # Resoudre les conflits manuellement
2 | # puis :
3 | git add fichiers - resolus
4 | git commit

5
6 | # Ou abandonner le merge :
7 | git merge -- abort

8
9 | # Ou avec rebase :
10 | git rebase -- abort
Alain Piallat | Formation GIT(51/57) | 13 janvier 2026

## Où trouver de l’aide ?

Ressources utiles :
- Documentation officielle : git-scm.com
- git help <commande> dans le terminal
- GitHub Learning Lab
- Stack Overflow
- Pro Git (livre gratuit : git-scm.com/book/en/v2)
Alain Piallat | Formation GIT(52/57) | 13 janvier 2026

## Interfaces graphiques

Il existe de nombreuses interfaces graphiques pour Git, facilitant son utilisation comme Git GUI qui est fourni avec Git. Par ailleurs, la plupart des IDE intègrent Git nativement (VSCode, IntelliJ, etc.)

Alain Piallat | Formation GIT(53/57) | 13 janvier 2026

## Documentation et tutoriels

Sites recommandés :
- git-scm.com - documentation officielle
- learngitbranching.js.org - tutoriel interactif
- github.com/github/gitignore - templates .gitignore
- choosealicense.com - choisir une licence
- Il existe beaucoup de tutoriels vidéo, guides et cours en ligne gratuits donc n’hésitez pas à chercher !
Alain Piallat | Formation GIT(54/57) | 13 janvier 2026

## Créer son profil GitHub/GitLab ♣

À faire :
- Créer un compte avec un nom professionnel
- Ajoutez vos projets personnels et scolaires (publics)
- Mettez un lien vers votre git dans votre CV/LinkedIn
- Votre GitHub/GitLab vous sert de portfolio technique
- Ajoutez votre adresse mail ENSEA (settings -> emails)
- Activer votre compte étudiant (settings -> billing and licensing -> education benefits)

Vous pouvez déjà mettre votre TP de microcontroleur pour avoir un début de profil

Alain Piallat | Formation GIT(55/57) | 13 janvier 2026

## Instant promotionnel

Avec Athéna, nous allons commencer des projets ce semestre l’ocasion de mettre en pratique vos compétences en GIT. La présentation de ces projets se fera Lundi prochain, à la même heure.

Des TDs peuvent également être organisés si vous êtes intéressés.

Formulaire d’inscription et de feedback :

Alain Piallat | Formation GIT(56/57) | 13 janvier 2026

## Remerciements

# Merci de votre attention !

Merci à Gauthier BIEHLER et Nicolas PAPAZOGLOU pour leur relecture et leurs suggestions.

### Des questions ?

N’hésitez pas à me contacter pour toute question ou suggestion d’amélioration de cette formation.

Alain Piallat | Formation GIT(57/57) | 13 janvier 2026

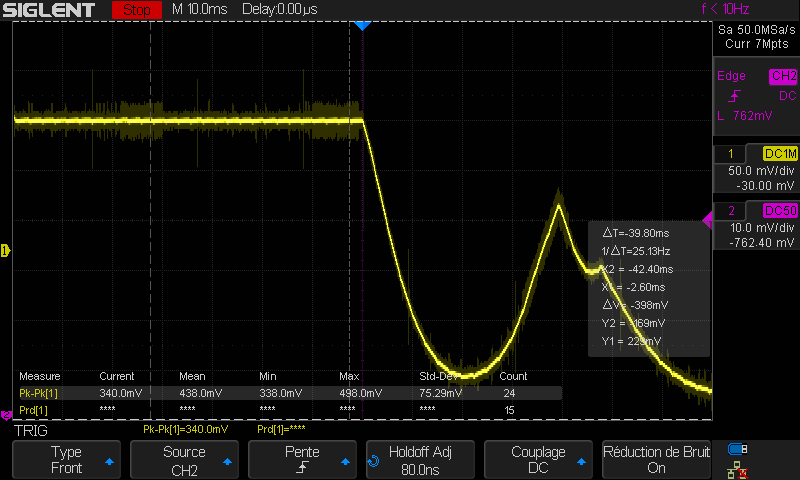
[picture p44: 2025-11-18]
Management/Image/IMG_Appel_de_courant.BMP

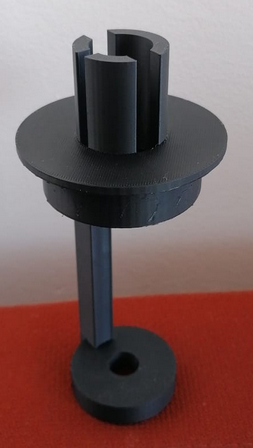
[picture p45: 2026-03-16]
Image/Bumper_imprimé.png

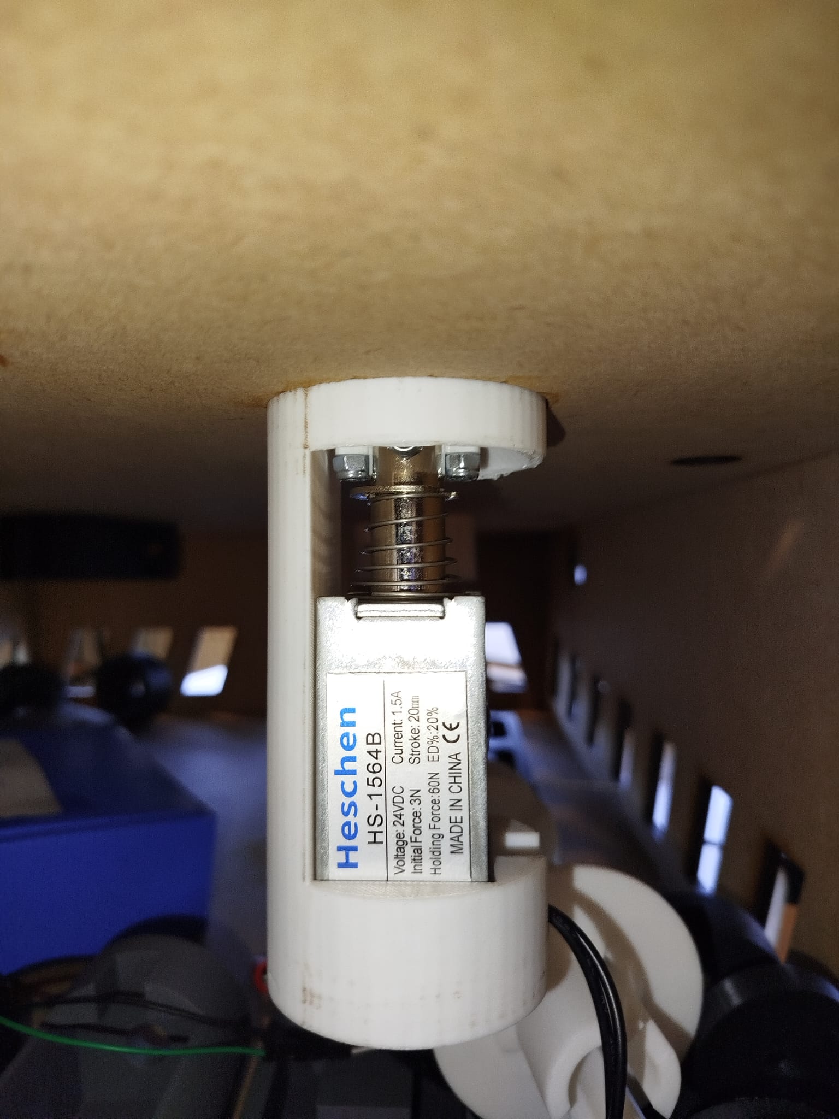
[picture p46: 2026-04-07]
Image/lower_bumber.jpeg

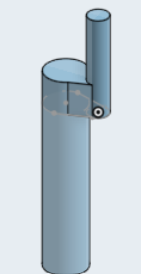
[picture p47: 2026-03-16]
Image/raccordement_onshape.png

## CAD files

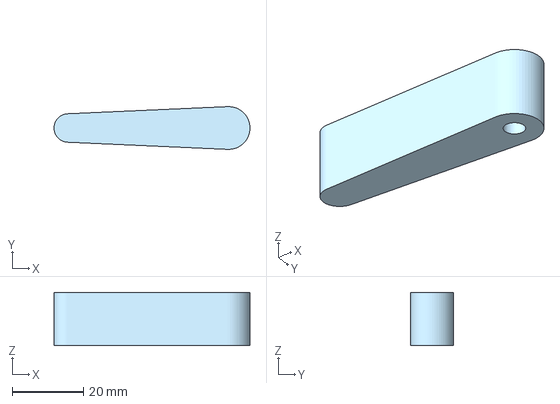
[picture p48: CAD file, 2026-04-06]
hardware/Modélisation 3D/Batteur/Batteur batteur avec écrou nylstop.3mf
55.0 x 12.0 x 15.0 mm

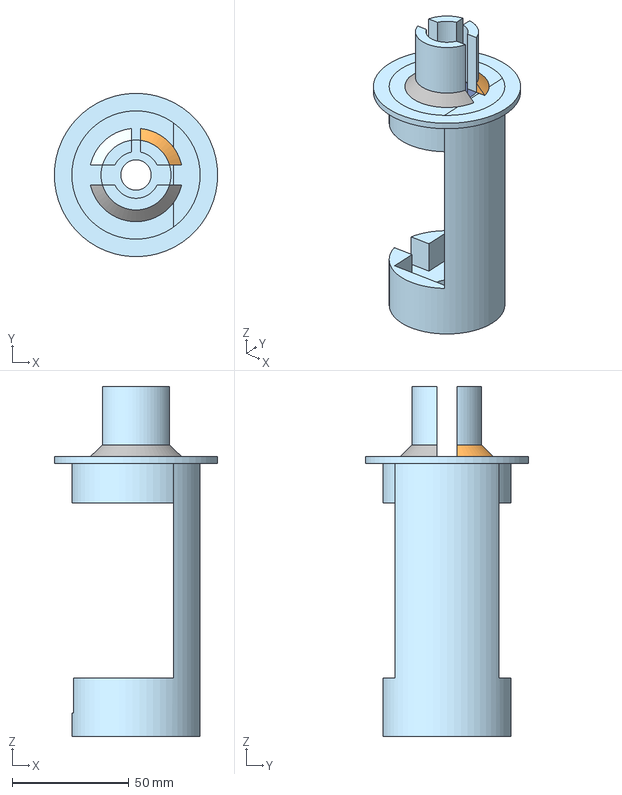
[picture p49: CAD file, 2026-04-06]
hardware/Modélisation 3D/Bumper/Bumper support Vfinal.3mf
70.0 x 69.9 x 150.0 mm
Surface 1
Surface 2
Surface 3

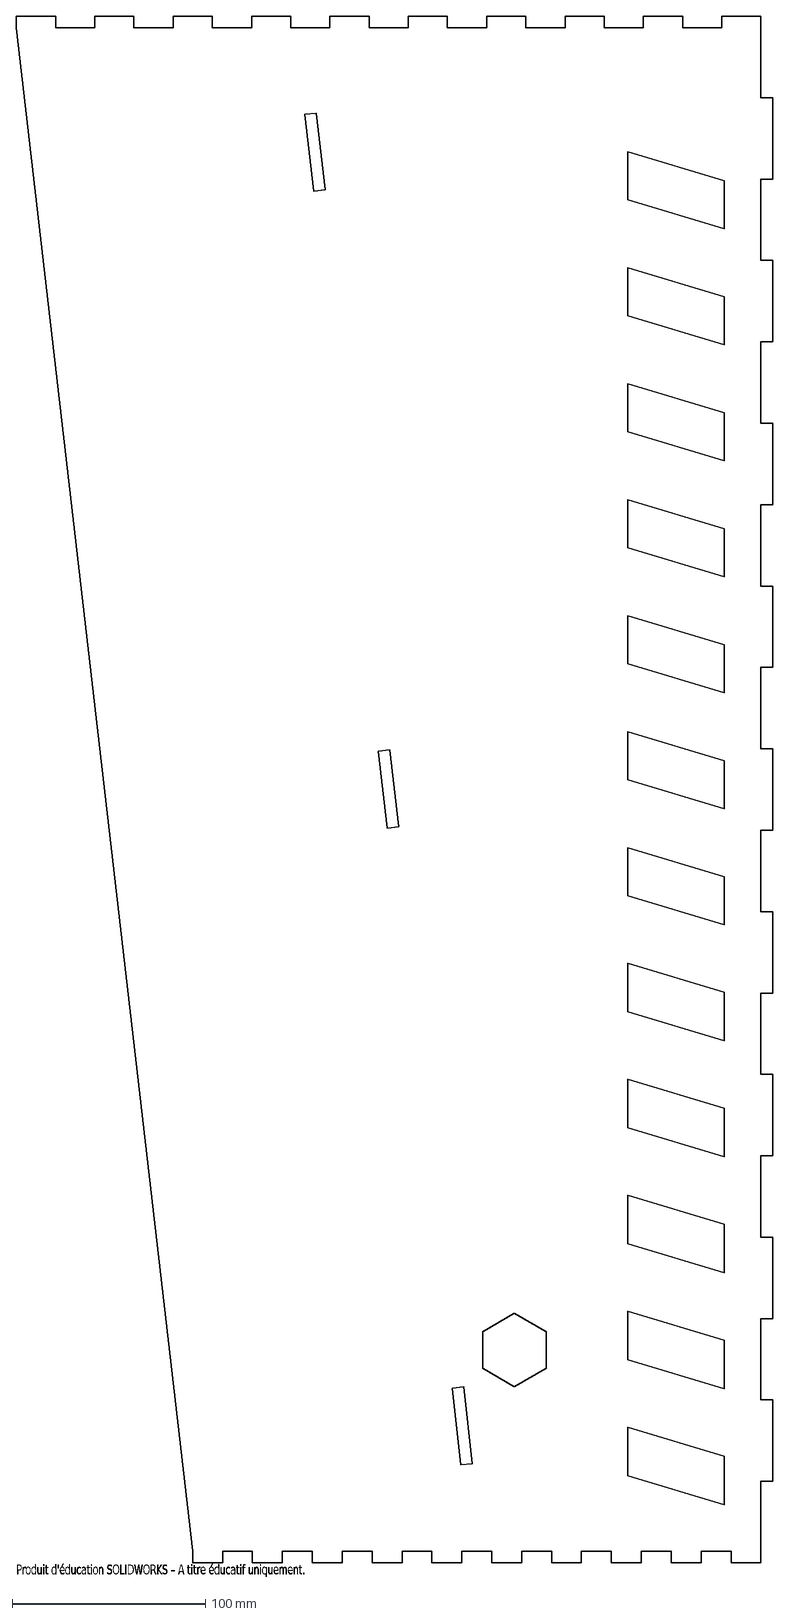
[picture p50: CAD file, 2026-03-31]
hardware/Modélisation 3D/Châssis/Découpeuse Laser/Châssis côté gauche_6mm_MDF.DXF
Produit d'éducation SOLIDWORKS – A titre éducatif uniquement.

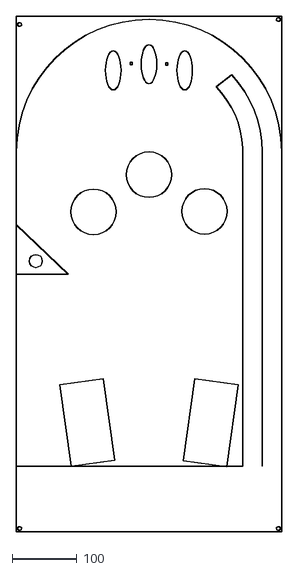
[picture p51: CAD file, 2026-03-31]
hardware/Modélisation 3D/Table jeux/Découpeuse laser/Table_3mm_MDF.dxf
408.0 x 793.2

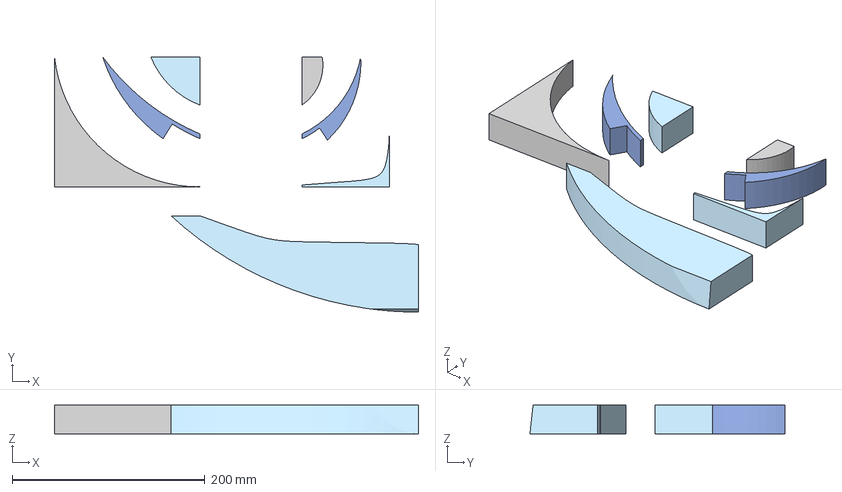
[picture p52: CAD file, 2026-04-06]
hardware/Modélisation 3D/Table jeux/Imprimante 3D/Bas table obstacle.3mf
378.0 x 265.0 x 30.0 mm

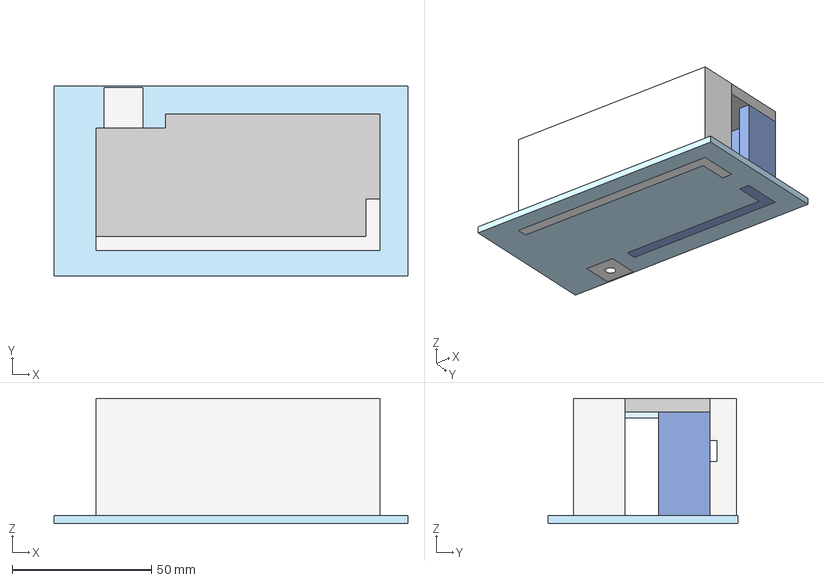
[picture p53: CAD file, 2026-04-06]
hardware/Modélisation 3D/Batteur/Batteur avec support Vfinal.3mf
127.0 x 68.0 x 45.0 mm

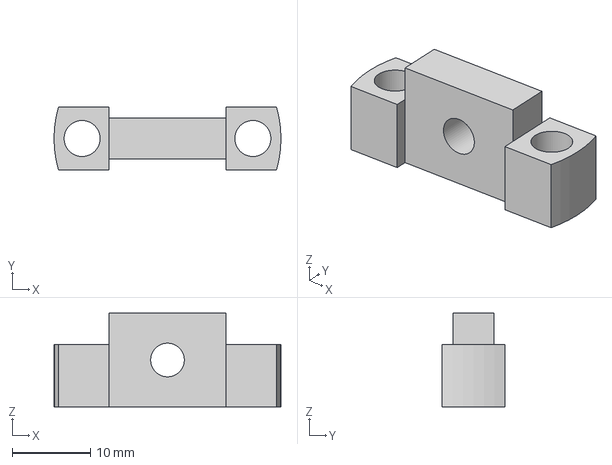
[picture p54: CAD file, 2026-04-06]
hardware/Modélisation 3D/Bumper/Bumper fixation solénoïde.3mf
29.0 x 8.00 x 12.0 mm

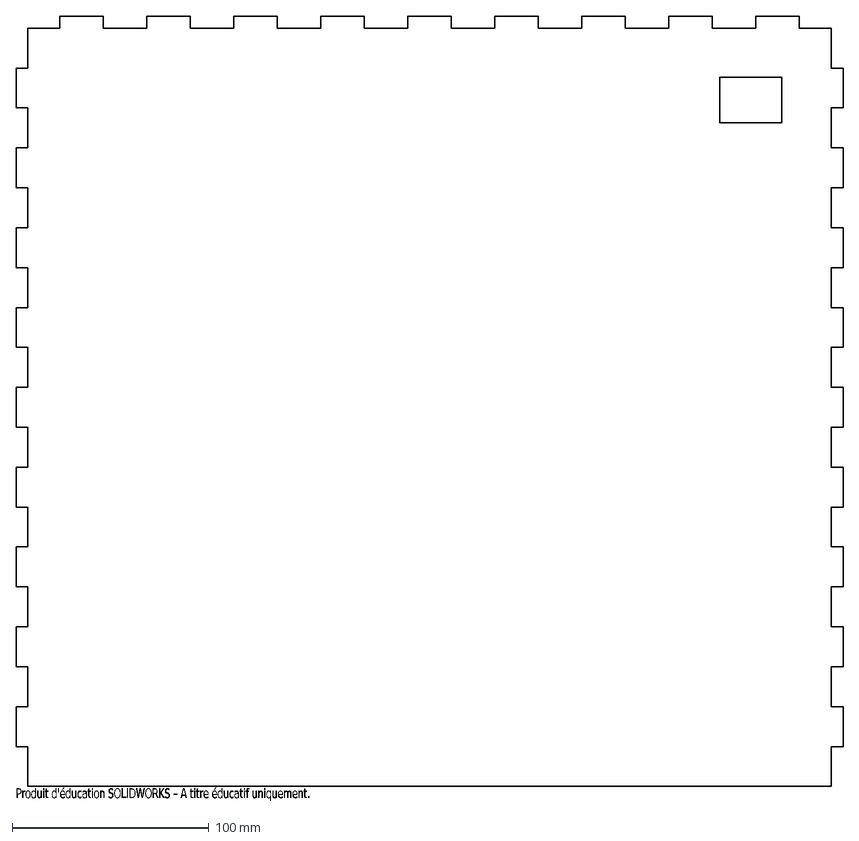
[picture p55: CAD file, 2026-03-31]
hardware/Modélisation 3D/Châssis/Découpeuse Laser/Châssis arrière_6mm_MDF.DXF
Produit d'éducation SOLIDWORKS – A titre éducatif uniquement.

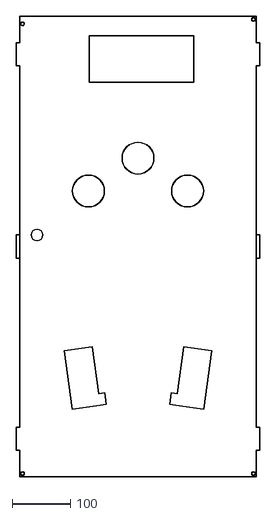
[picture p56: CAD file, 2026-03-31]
hardware/Modélisation 3D/Table jeux/Découpeuse laser/Table_6mm_MDF.dxf
420.0 x 793.2

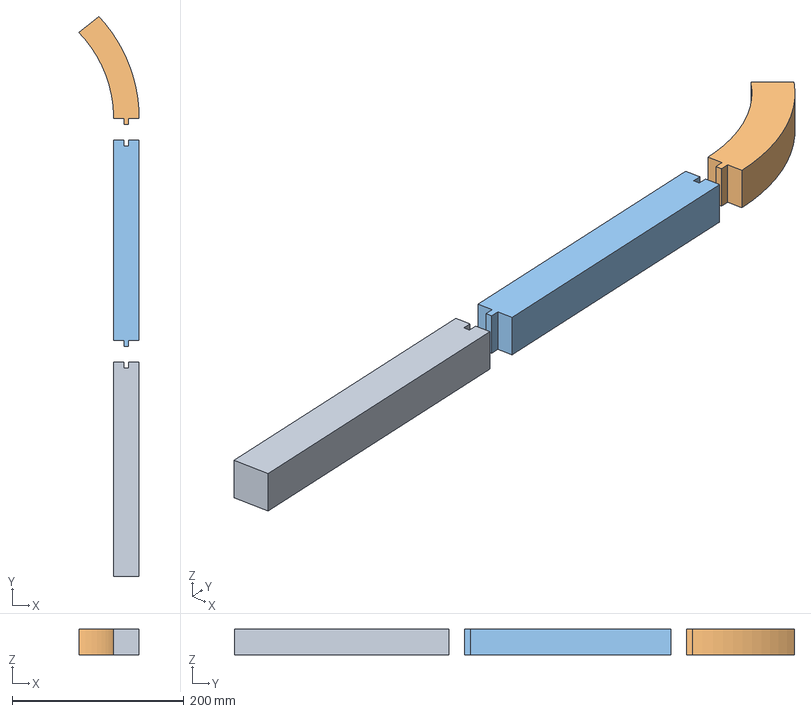
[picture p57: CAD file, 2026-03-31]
hardware/Modélisation 3D/Table jeux/Imprimante 3D/Rampe obstacle.3mf
70.5 x 653.0 x 30.0 mm

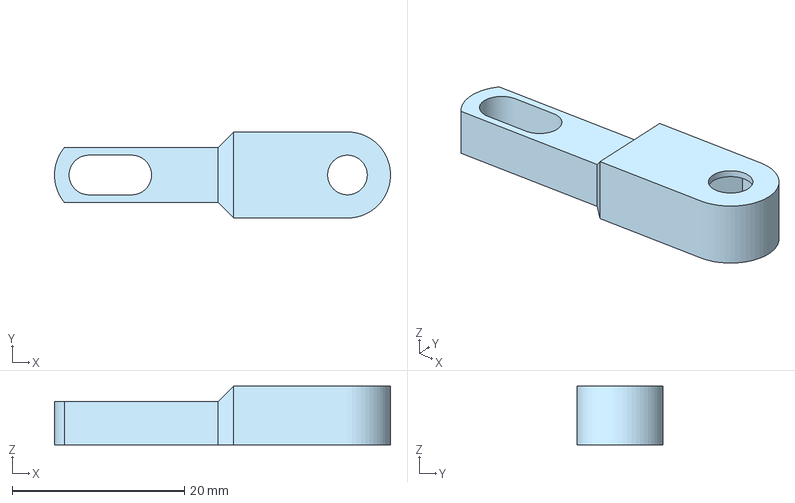
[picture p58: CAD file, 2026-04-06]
hardware/Modélisation 3D/Batteur/Batteur bras de levier avec écrou nylstop.3mf
39.0 x 10.0 x 6.80 mm

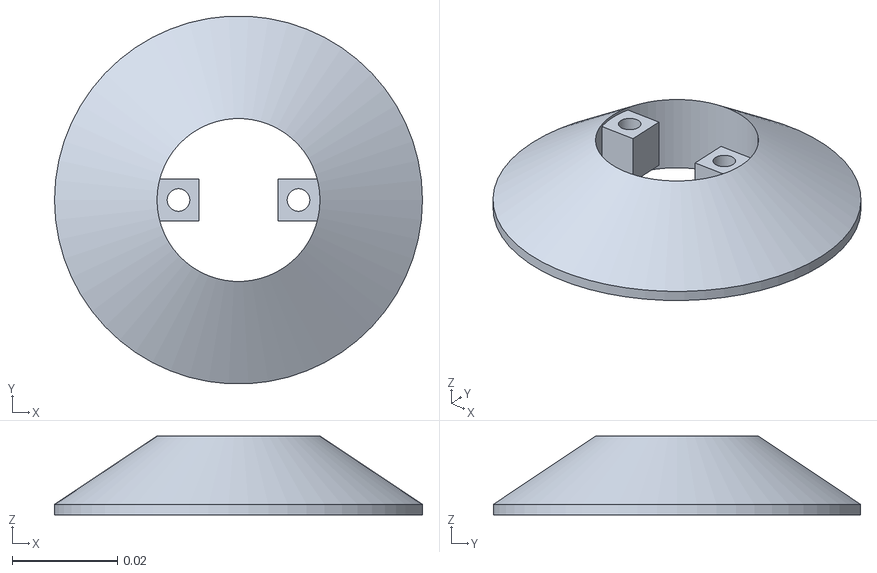
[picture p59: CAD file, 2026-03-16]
hardware/Modélisation 3D/Bumper/Bumper collerette.stl
0.07 x 0.0699 x 0.015

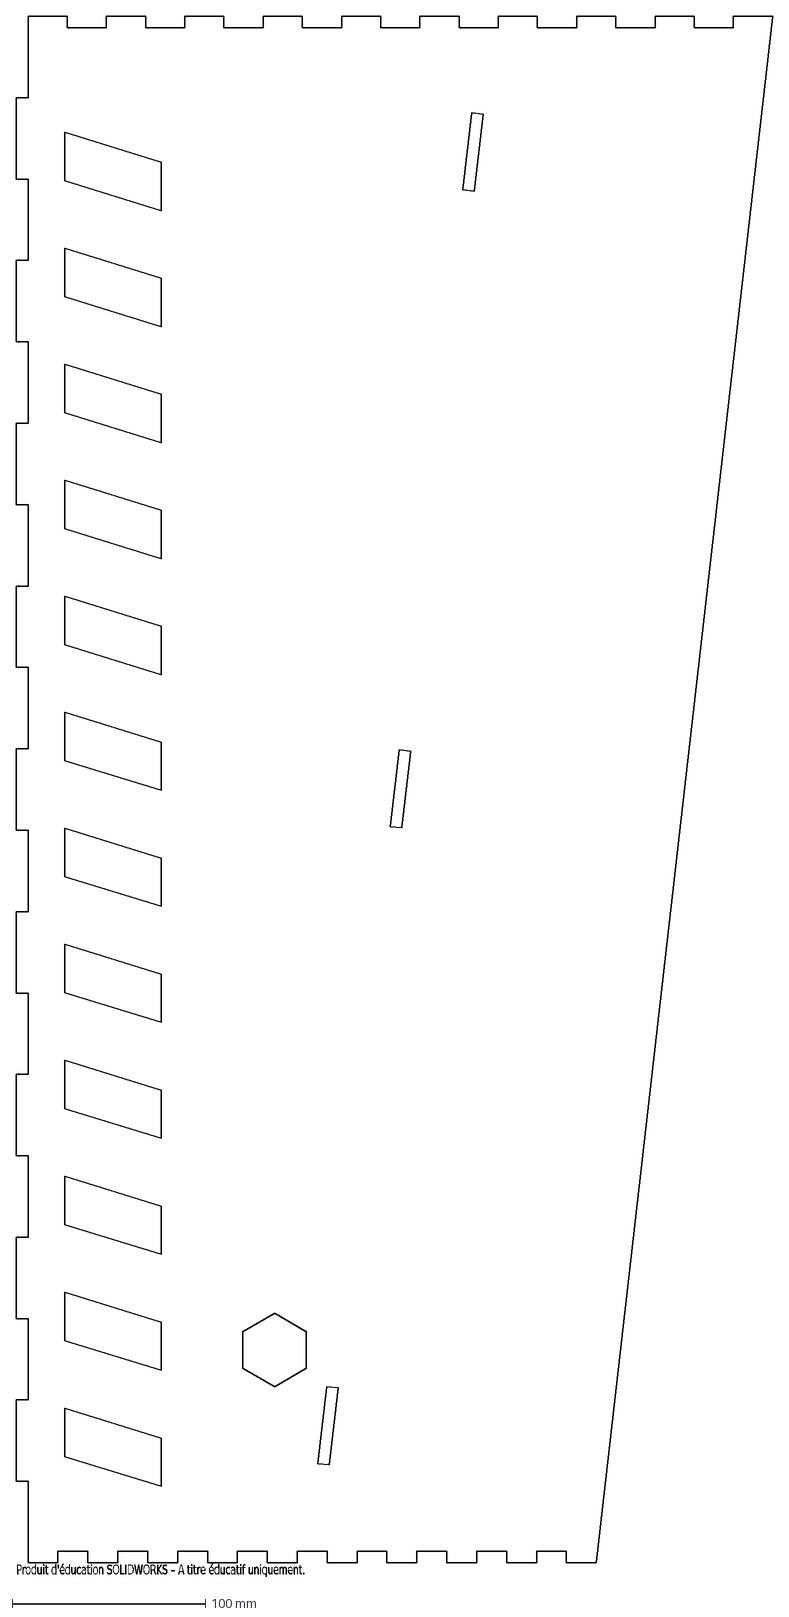
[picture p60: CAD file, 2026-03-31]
hardware/Modélisation 3D/Châssis/Découpeuse Laser/Châssis côté droit_6mm_MDF.DXF
Produit d'éducation SOLIDWORKS – A titre éducatif uniquement.

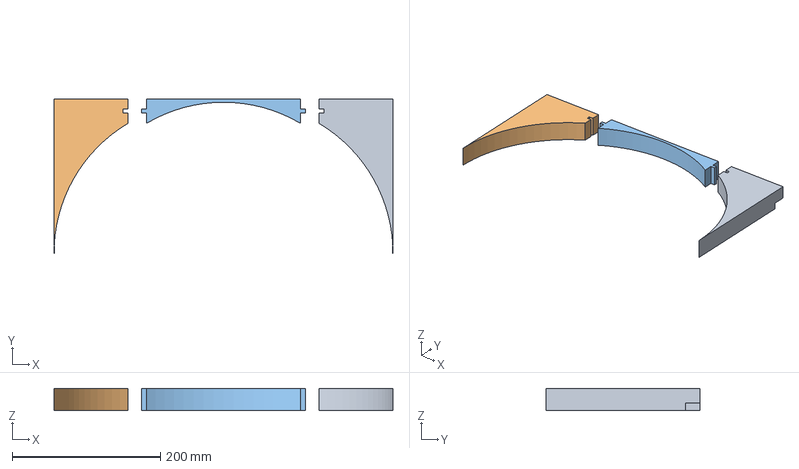
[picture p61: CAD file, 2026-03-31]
hardware/Modélisation 3D/Table jeux/Imprimante 3D/Haut table obstacle.3mf
458.0 x 208.7 x 30.0 mm

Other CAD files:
hardware/Modélisation 3D/Bumper/Bumper support V2.stl
hardware/Modélisation 3D/Châssis/Découpeuse Laser/Châssis avant_6mm_MDF.DXF
hardware/Modélisation 3D/Batteur/Batteur bras de levier avec écrou.stl
hardware/Modélisation 3D/Batteur/Batteur avec Support V2.stl
hardware/Modélisation 3D/Batteur/Batteur avec support V1.stl
hardware/Modélisation 3D/Batteur/Batteur batteur avec écrou.stl
hardware/Modélisation 3D/Bumper/Bumper support V1.3mf
hardware/Modélisation 3D/Châssis/Découpeuse Laser/Châssis fond_6mm_MDF.DXF
hardware/Modélisation 3D/Table jeux/Imprimante 3D/Triangle obstacle.3mf

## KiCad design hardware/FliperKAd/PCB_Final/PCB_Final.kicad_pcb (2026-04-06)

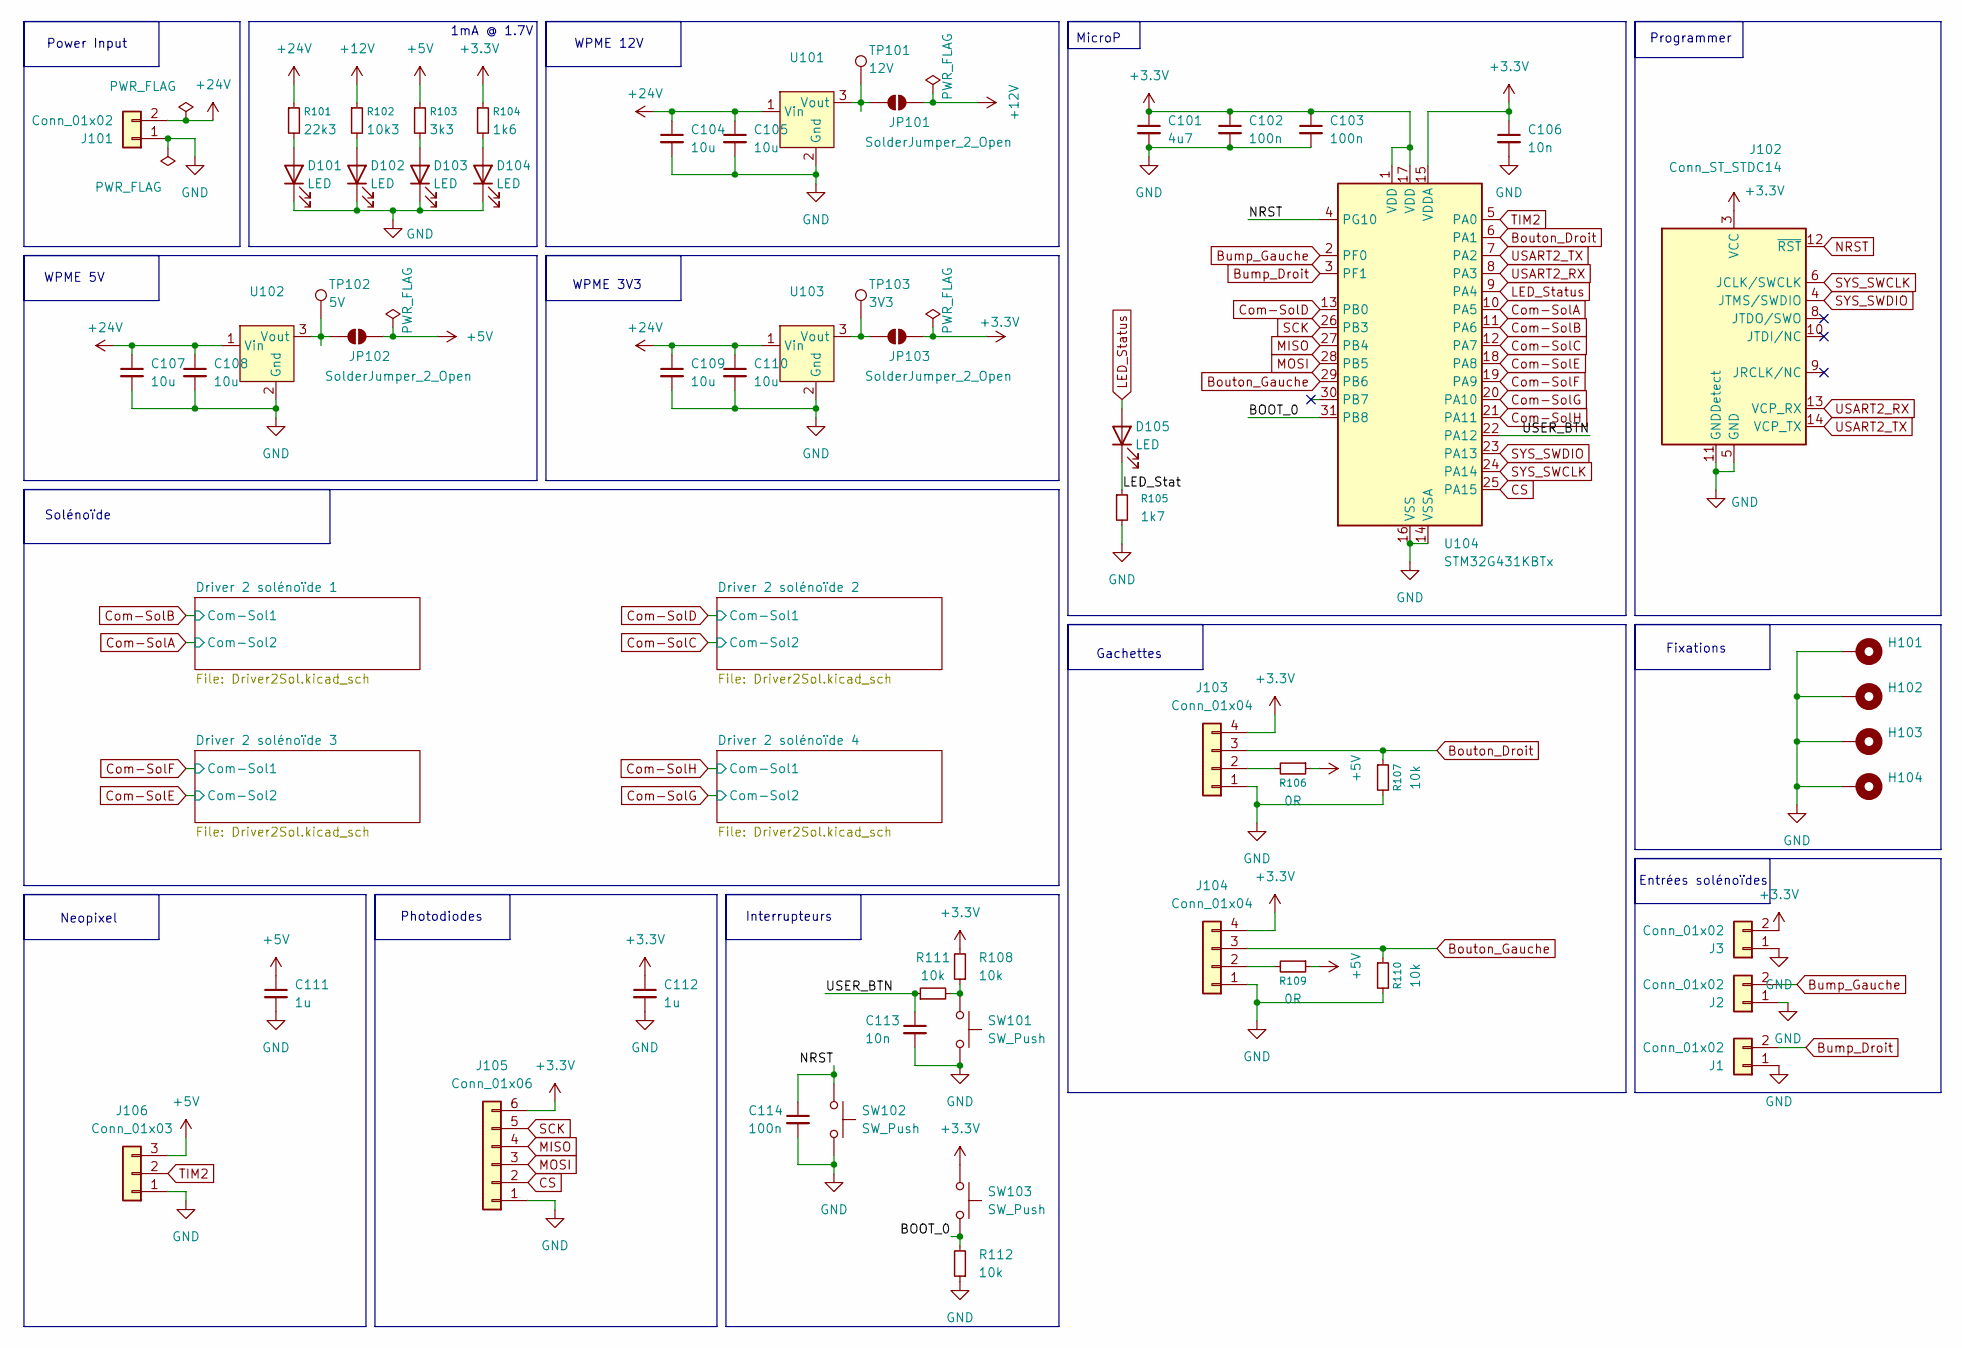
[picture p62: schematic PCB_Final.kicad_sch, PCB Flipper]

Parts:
C101: 4u7; C_0603_1608Metric
C102, C103, C114: 100n; C_0402_1005Metric
C104, C105, C107, C108, C109, C110: 10u; C_1206_3216Metric
C106, C113: 10n; C_0402_1005Metric
C111, C112: 1u; C_0603_1608Metric
D101: LED; LED_0603_1608Metric; MPN 150060RS55040
D102, D103, D104, D105: LED; LED_0603_1608Metric
H101, H102, H103, H104: MountingHole_Pad; MountingHole_3.2mm_M3_Pad_Via
J1, J2, J3: Conn_01x02; JST_PH_B2B-PH-K_1x02_P2.00mm_Vertical
J101: Conn_01x02; AMASS_XT30U-F_1x02_P5.0mm_Vertical
J102: Conn_ST_STDC14; PinHeader_2x07_P1.27mm_Vertical_SMD
J103, J104: Conn_01x04; JST_PH_B4B-PH-K_1x04_P2.00mm_Vertical
J105: Conn_01x06; JST_PH_B6B-PH-K_1x06_P2.00mm_Vertical
J106: Conn_01x03; JST_PH_B3B-PH-K_1x03_P2.00mm_Vertical
JP101, JP102, JP103: SolderJumper_2_Open; SolderJumper-2_P1.3mm_Open_TrianglePad1.0x1.5mm
R101: 22k3; R_0402_1005Metric
R102: 10k3; R_0402_1005Metric
R103: 3k3; R_0402_1005Metric
R104: 1k6; R_0402_1005Metric
R105: 1k7; R_0402_1005Metric
R106, R109: 0R; R_0402_1005Metric
R107, R108, R110, R111, R112: 10k; R_0402_1005Metric
SW101, SW102, SW103: SW_Push; SW_SPST_B3U-3000P; MPN KSS221GLFS
TP101: 12V; TestPoint_Pad_D2.0mm
TP102: 5V; TestPoint_Pad_D2.0mm
TP103: 3V3; TestPoint_Pad_D2.0mm
U101: 173951275; MPN 173951275
U102: 173951275; MPN 173950575
U103: 173951275; MPN 173950375
U104: STM32G431KBTx; LQFP-32_7x7mm_P0.8mm

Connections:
+3.3V: C101.1, C102.1, C103.1, C106.1, C112.1, J3.2, J102.3 (VCC), J103.4, J104.4, J105.6, JP103.2 (B), R104.1, R108.2, SW103.1, U104.1 (VDD), U104.15 (VDDA), U104.17 (VDD)
+5V: C111.1, J106.3, JP102.2 (B), R103.1, R106.1, R109.1
+12V: JP101.2 (B), R102.1; also elsewhere on the board
+24V: C104.1, C105.1, C107.1, C108.1, C109.1, C110.1, J101.2, R101.1, U101.1 (Vin), U102.1 (Vin), U103.1 (Vin); also elsewhere on the board
/BOOT_0: R112.2, SW103.2, U104.31 (PB8)
/LED_Stat: D105.1 (K), R105.1
/USER_BTN: C113.1, R111.1, U104.22 (PA12)
Bouton_Droit: J103.3, R107.1, U104.6 (PA1)
Bouton_Gauche: J104.3, R110.1, U104.29 (PB6)
Bump_Droit: J1.2, U104.3 (PF1)
Bump_Gauche: J2.2, U104.2 (PF0)
CS: J105.2, U104.25 (PA15)
Com-SolA: U104.10 (PA5); also elsewhere on the board
Com-SolB: U104.11 (PA6); also elsewhere on the board
Com-SolC: U104.12 (PA7); also elsewhere on the board
Com-SolD: U104.13 (PB0); also elsewhere on the board
Com-SolE: U104.18 (PA8); also elsewhere on the board
Com-SolF: U104.19 (PA9); also elsewhere on the board
Com-SolG: U104.20 (PA10); also elsewhere on the board
Com-SolH: U104.21 (PA11); also elsewhere on the board
GND: C101.2, C102.2, C103.2, C104.2, C105.2, C106.2, C107.2, C108.2, C109.2, C110.2, C111.2, C112.2, C113.2, C114.2, D101.1 (K), D102.1 (K), D103.1 (K), D104.1 (K), H101.1, H102.1, H103.1, H104.1, J1.1, J2.1, J3.1, J101.1, J102.5 (GND), J102.7 (GND), J102.11 (GNDDetect), J103.1, J104.1, J105.1, J106.1, R105.2, R107.2, R110.2, R112.1, SW101.2, SW102.2, U101.2 (Gnd), U102.2 (Gnd), U103.2 (Gnd), U104.14 (VSSA), U104.16 (VSS), U104.32 (VSS); also elsewhere on the board
LED_Status: D105.2 (A), U104.9 (PA4)
MISO: J105.4, U104.27 (PB4)
MOSI: J105.3, U104.28 (PB5)
NRST: C114.1, J102.12 (~RST), SW102.1, U104.4 (PG10)
unnamed: D101.2 (A), R101.2
unnamed: D102.2 (A), R102.2
unnamed: D103.2 (A), R103.2
unnamed: D104.2 (A), R104.2
unnamed: J103.2, R106.2
unnamed: J104.2, R109.2
unnamed: JP101.1 (A), TP101.1, U101.3 (Vout)
unnamed: JP102.1 (A), TP102.1, U102.3 (Vout)
unnamed: JP103.1 (A), TP103.1, U103.3 (Vout)
unnamed: R108.1, R111.2, SW101.1
SCK: J105.5, U104.26 (PB3)
SYS_SWCLK: J102.6 (JCLK/SWCLK), U104.24 (PA14)
SYS_SWDIO: J102.4 (JTMS/SWDIO), U104.23 (PA13)
TIM2: J106.2, U104.5 (PA0)
USART2_RX: J102.13 (VCP_RX), U104.8 (PA3)
USART2_TX: J102.14 (VCP_TX), U104.7 (PA2)

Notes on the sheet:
Entrées solénoïdes
Interrupteurs
1mA @ 1.7V
Neopixel
Fixations
MicroP
Solénoïde
WPME 12V
Programmer
WPME 5V
Power Input
WPME 3V3
Gachettes
Photodiodes

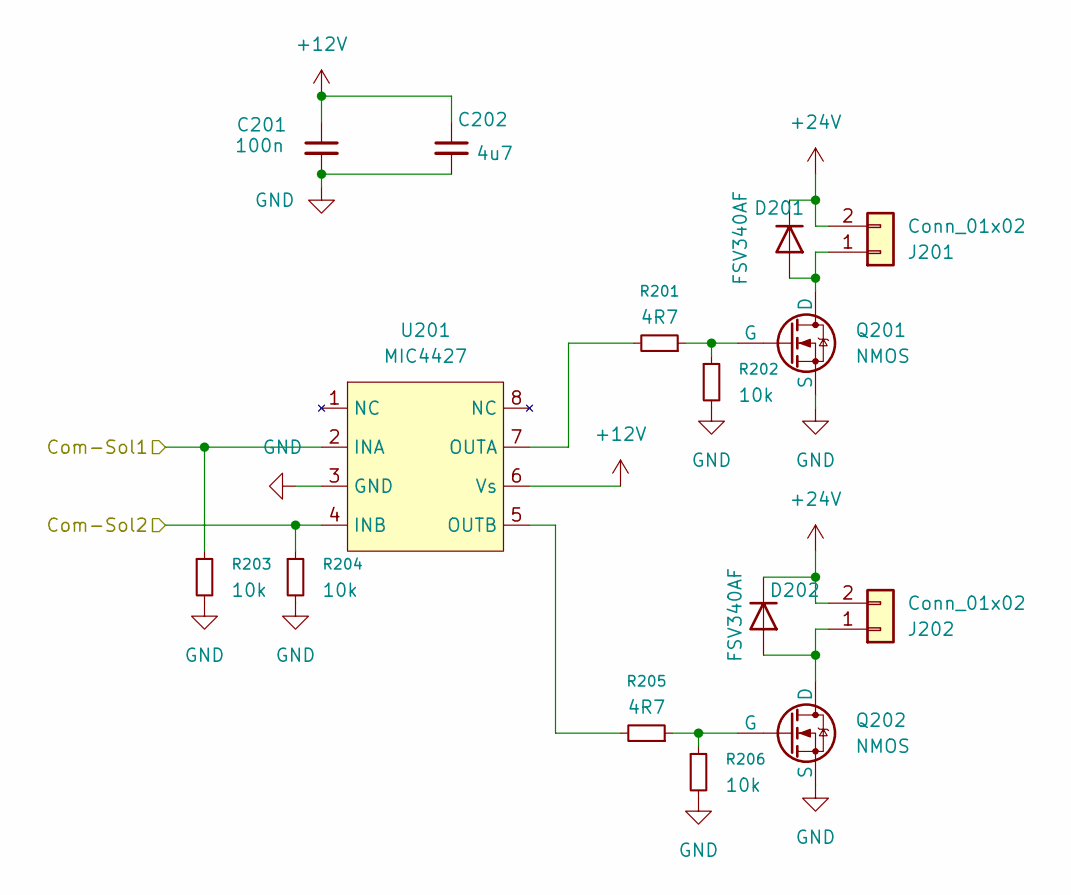
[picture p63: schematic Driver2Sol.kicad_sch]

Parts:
C201: 100n; C_0402_1005Metric
C202: 4u7; C_0603_1608Metric
D201, D202: FSV340AF; D_SMA
J201, J202: Conn_01x02; JST_PH_B2B-PH-K_1x02_P2.00mm_Vertical
Q201, Q202: NMOS; BUK
R201, R205: 4R7; R_0402_1005Metric
R202, R203, R204, R206: 10k; R_0402_1005Metric
U201: MIC4427; SOIC-8_5.3x6.2mm_P1.27mm; MPN MIC4427

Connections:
+12V: C201.1, C202.1, U201.6 (Vs); also elsewhere on the board
+24V: D201.1 (K), D202.1 (K), J201.2, J202.2; also elsewhere on the board
Com-SolA: R204.1, U201.4 (INB); also elsewhere on the board
Com-SolB: R203.1, U201.2 (INA); also elsewhere on the board
GND: C201.2, C202.2, Q201.3 (S), Q202.3 (S), R202.2, R203.2, R204.2, R206.2, U201.3 (GND); also elsewhere on the board
unnamed: D201.2 (A), J201.1, Q201.1 (D)
unnamed: D202.2 (A), J202.1, Q202.1 (D)
unnamed: Q201.2 (G), R201.1, R202.1
unnamed: Q202.2 (G), R205.1, R206.1
unnamed: R201.2, U201.7 (OUTA)
unnamed: R205.2, U201.5 (OUTB)

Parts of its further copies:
C301, C401, C501: 100n; C_0402_1005Metric
C302, C402, C502: 4u7; C_0603_1608Metric
D301, D302, D401, D402, D501, D502: FSV340AF; D_SMA
J301, J302, J401, J402, J501, J502: Conn_01x02; JST_PH_B2B-PH-K_1x02_P2.00mm_Vertical
Q301, Q302, Q401, Q402, Q501, Q502: NMOS; BUK
R301, R305, R401, R405, R501, R505: 4R7; R_0402_1005Metric
R302, R303, R304, R306, R402, R403, R404, R406, R502, R503, R504, R506: 10k; R_0402_1005Metric
U301, U401, U501: MIC4427; SOIC-8_5.3x6.2mm_P1.27mm; MPN MIC4427

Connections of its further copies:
+12V: C301.1, C302.1, C401.1, C402.1, C501.1, C502.1, U301.6 (Vs), U401.6 (Vs), U501.6 (Vs); also elsewhere on the board
+24V: D301.1 (K), D302.1 (K), D401.1 (K), D402.1 (K), D501.1 (K), D502.1 (K), J301.2, J302.2, J401.2, J402.2, J501.2, J502.2; also elsewhere on the board
Com-SolC: R304.1, U301.4 (INB); also elsewhere on the board
Com-SolD: R303.1, U301.2 (INA); also elsewhere on the board
Com-SolE: R404.1, U401.4 (INB); also elsewhere on the board
Com-SolF: R403.1, U401.2 (INA); also elsewhere on the board
Com-SolG: R504.1, U501.4 (INB); also elsewhere on the board
Com-SolH: R503.1, U501.2 (INA); also elsewhere on the board
GND: C301.2, C302.2, C401.2, C402.2, C501.2, C502.2, Q301.3 (S), Q302.3 (S), Q401.3 (S), Q402.3 (S), Q501.3 (S), Q502.3 (S), R302.2, R303.2, R304.2, R306.2, R402.2, R403.2, R404.2, R406.2, R502.2, R503.2, R504.2, R506.2, U301.3 (GND), U401.3 (GND), U501.3 (GND); also elsewhere on the board
unnamed: D301.2 (A), J301.1, Q301.1 (D)
unnamed: D302.2 (A), J302.1, Q302.1 (D)
unnamed: D401.2 (A), J401.1, Q401.1 (D)
unnamed: D402.2 (A), J402.1, Q402.1 (D)
unnamed: D501.2 (A), J501.1, Q501.1 (D)
unnamed: D502.2 (A), J502.1, Q502.1 (D)
unnamed: Q301.2 (G), R301.1, R302.1
unnamed: Q302.2 (G), R305.1, R306.1
unnamed: Q401.2 (G), R401.1, R402.1
unnamed: Q402.2 (G), R405.1, R406.1
unnamed: Q501.2 (G), R501.1, R502.1
unnamed: Q502.2 (G), R505.1, R506.1
unnamed: R301.2, U301.7 (OUTA)
unnamed: R305.2, U301.5 (OUTB)
unnamed: R401.2, U401.7 (OUTA)
unnamed: R405.2, U401.5 (OUTB)
unnamed: R501.2, U501.7 (OUTA)
unnamed: R505.2, U501.5 (OUTB)

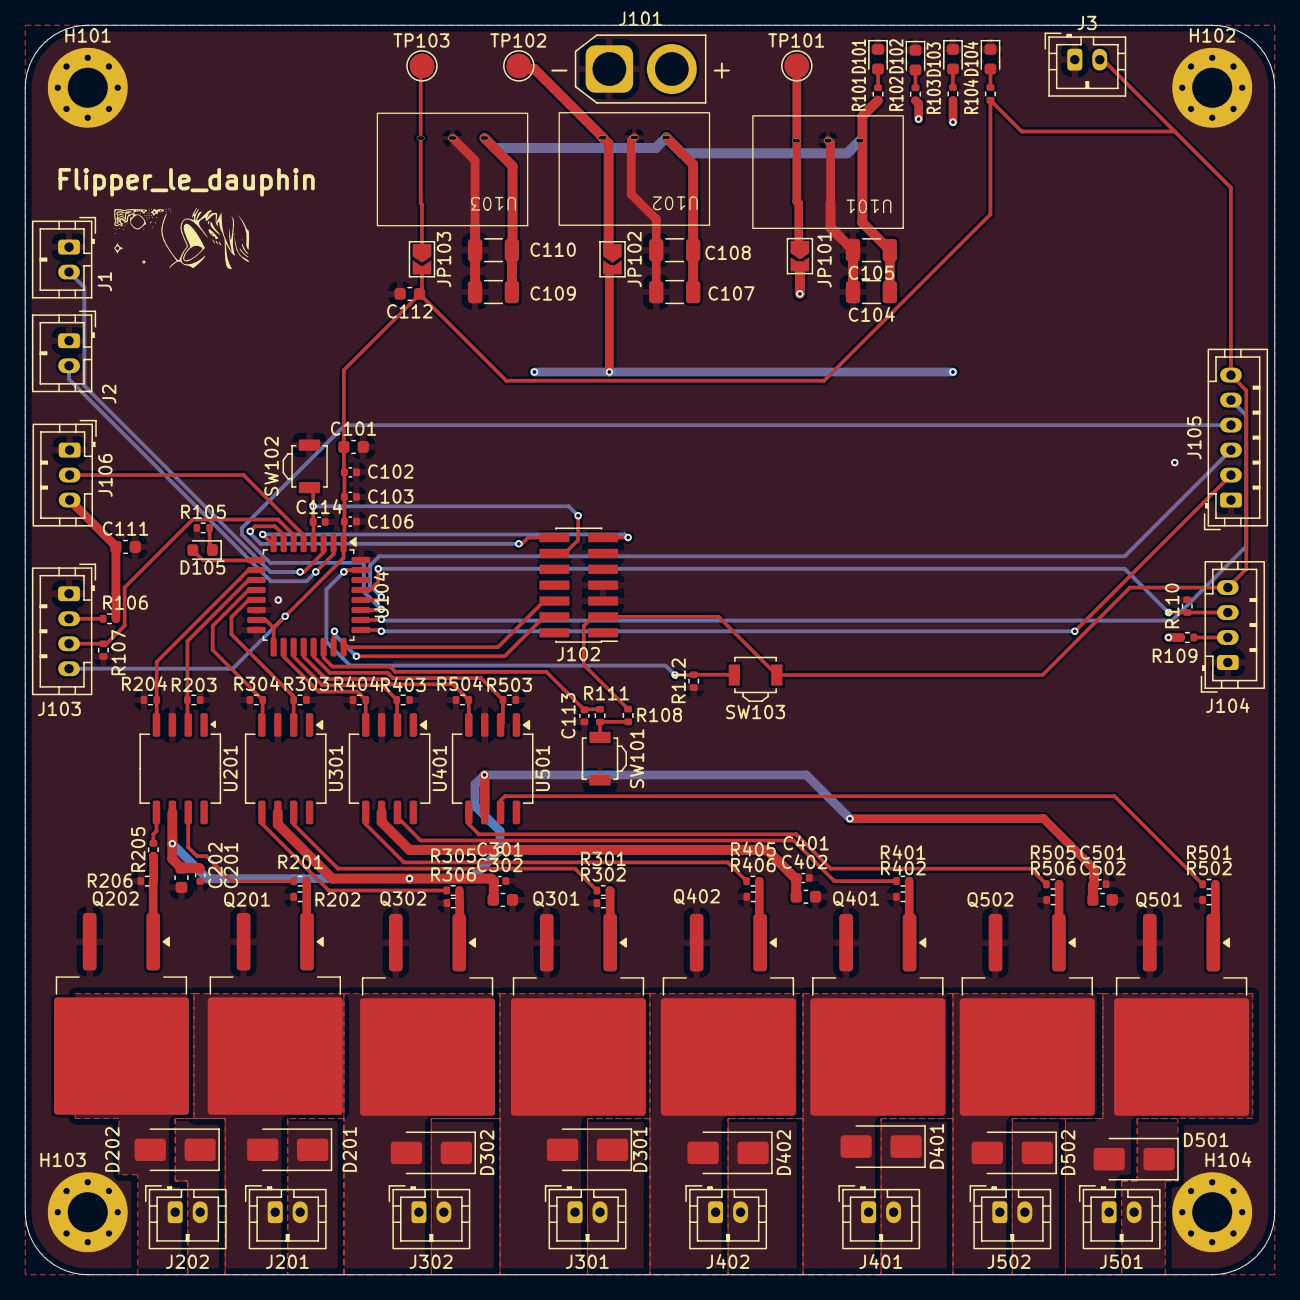
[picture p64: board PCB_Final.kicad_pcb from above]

Board: 4 copper layers, 100.0 x 100.0 mm, 117 parts (0 on the bottom side), 65 nets.

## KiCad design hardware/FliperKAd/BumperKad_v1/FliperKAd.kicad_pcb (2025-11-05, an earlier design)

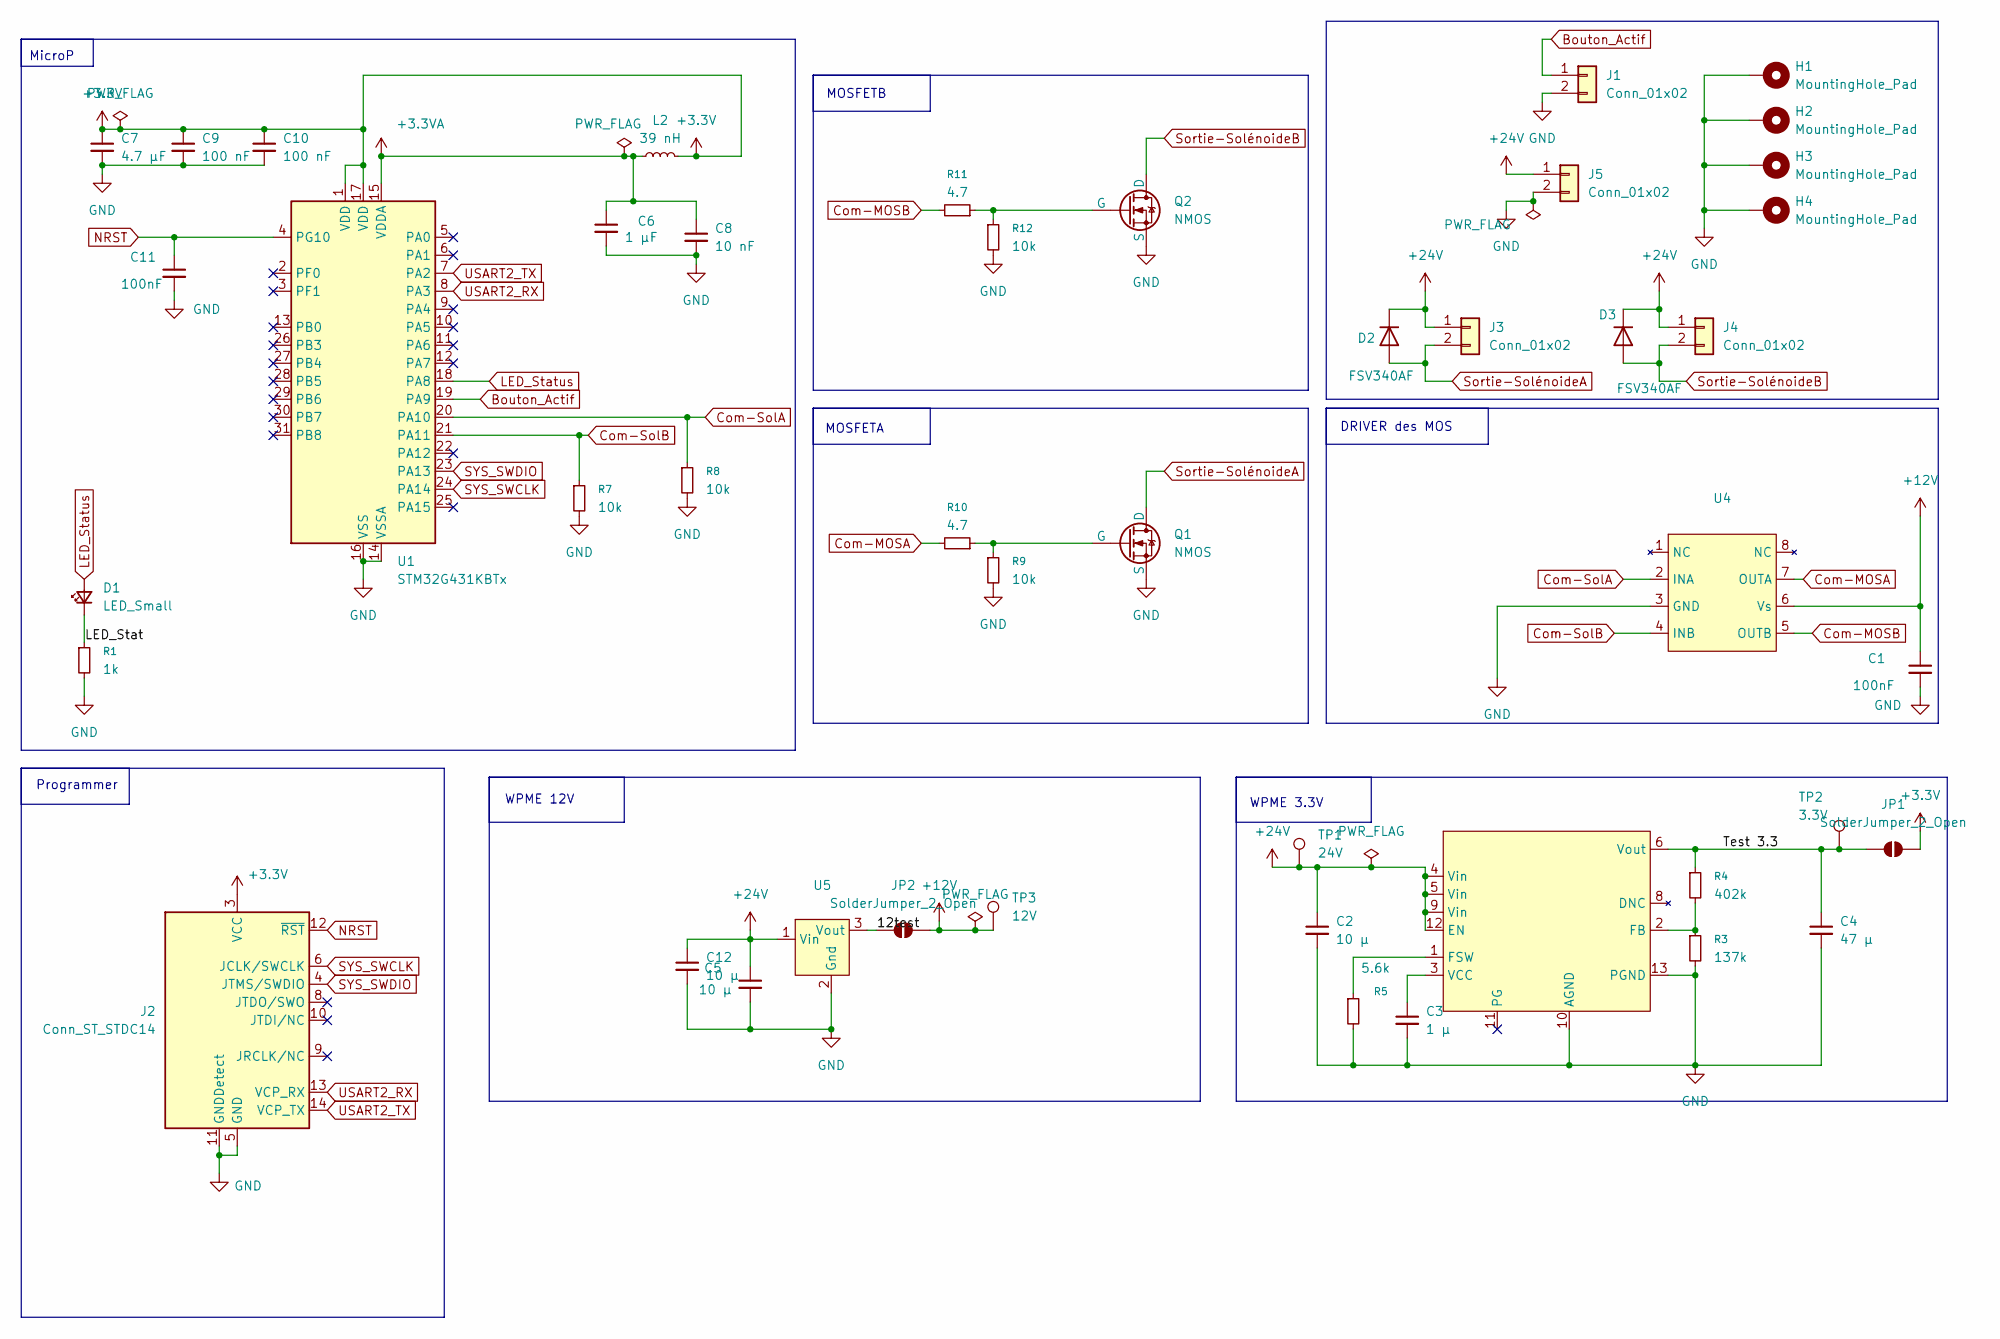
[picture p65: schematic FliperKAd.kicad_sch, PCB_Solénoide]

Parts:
C1, C11: 100nF; C_0603_1608Metric
C2, C5, C12: 10 µ; C_0603_1608Metric
C3: 1 µ; C_0603_1608Metric
C4: 47 µ; C_0603_1608Metric
C6: 1 µF; C_0603_1608Metric
C7: 4.7 µF; C_0603_1608Metric
C8: 10 nF; C_0402_1005Metric
C9, C10: 100 nF; C_0402_1005Metric
D1: LED_Small; LED_0603_1608Metric
D2, D3: FSV340AF; D_SMA
H1, H2, H3, H4: MountingHole_Pad; MountingHole_3.2mm_M3_Pad_Via
J1, J3, J4, J5: Conn_01x02; JST_XH_B2B-XH-A_1x02_P2.50mm_Vertical
J2: Conn_ST_STDC14; PinHeader_2x07_P1.27mm_Vertical_SMD
JP1, JP2: SolderJumper_2_Open; SolderJumper-2_P1.3mm_Open_TrianglePad1.0x1.5mm
L2: 39 nH; L_0603_1608Metric
Q1, Q2: NMOS; TO-263-3_TabPin2
R1: 1k; R_0603_1608Metric
R3: 137k; R_0603_1608Metric
R4: 402k; R_0603_1608Metric
R5: 5.6k; R_0603_1608Metric
R7, R8, R9, R12: 10k; R_0603_1608Metric
R10, R11: 4.7; R_0603_1608Metric
TP1: 24V; TestPoint_Pad_D2.0mm
TP2: 3.3V; TestPoint_Pad_D2.0mm
TP3: 12V; TestPoint_Pad_D2.0mm
U1: STM32G431KBTx; LQFP-32_7x7mm_P0.8mm
U3: MCP1640x-xMC; WPME_Magic
U4: MIC4426
U5: 173951275

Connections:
+3.3V: C7.1, C9.1, C10.1, J2.3 (VCC), JP1.2 (B), L2.2, U1.1 (VDD), U1.17 (VDD)
+3.3VA: C6.1, C8.1, L2.1, U1.15 (VDDA)
+12V: C1.1, JP2.2 (B), TP3.1, U4.6 (Vs)
+24V: C2.1, C5.1, C12.1, D2.1 (K), D3.1 (K), J3.1, J4.1, J5.1, TP1.1, U3.4 (Vin), U3.5 (Vin), U3.9 (Vin), U3.12 (EN), U5.1 (Vin)
/12test: JP2.1 (A), U5.3 (Vout)
/LED_Stat: D1.1 (K), R1.1
/Test 3.3: C4.1, JP1.1 (A), R4.1, TP2.1, U3.6 (Vout), U3.7 (Vout)
Bouton_Actif: J1.1, U1.19 (PA9)
Com-MOSA: R10.2, U4.7 (OUTA)
Com-MOSB: R11.2, U4.5 (OUTB)
Com-SolA: R8.1, U1.20 (PA10), U4.2 (INA)
Com-SolB: R7.1, U1.21 (PA11), U4.4 (INB)
GND: C1.2, C2.2, C3.2, C4.2, C5.2, C6.2, C7.2, C8.2, C9.2, C10.2, C11.2, C12.2, H1.1, H2.1, H3.1, H4.1, J1.2, J2.5 (GND), J2.7 (GND), J2.11 (GNDDetect), J5.2, Q1.3 (S), Q2.3 (S), R1.2, R3.2, R5.2, R7.2, R8.2, R9.2, R12.2, U1.14 (VSSA), U1.16 (VSS), U1.32 (VSS), U3.10 (AGND), U3.13 (PGND), U4.3 (GND), U5.2 (Gnd)
LED_Status: D1.2 (A), U1.18 (PA8)
NRST: C11.1, J2.12 (~RST), U1.4 (PG10)
unnamed: Q1.2 (G), R9.1, R10.1
unnamed: Q2.2 (G), R11.1, R12.1
unnamed: R3.1, R4.2, U3.2 (FB)
unnamed: R5.1, U3.1 (FSW)
unnamed: C3.1, U3.3 (VCC)
SYS_SWCLK: J2.6 (JCLK/SWCLK), U1.24 (PA14)
SYS_SWDIO: J2.4 (JTMS/SWDIO), U1.23 (PA13)
Sortie-SolénoideA: D2.2 (A), J3.2, Q1.1 (D)
Sortie-SolénoideB: D3.2 (A), J4.2, Q2.1 (D)
USART2_RX: J2.13 (VCP_RX), U1.8 (PA3)
USART2_TX: J2.14 (VCP_TX), U1.7 (PA2)

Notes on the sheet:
MOSFETB
WPME 3.3V
WPME 12V
DRIVER des MOS
MicroP
MOSFETA
Programmer

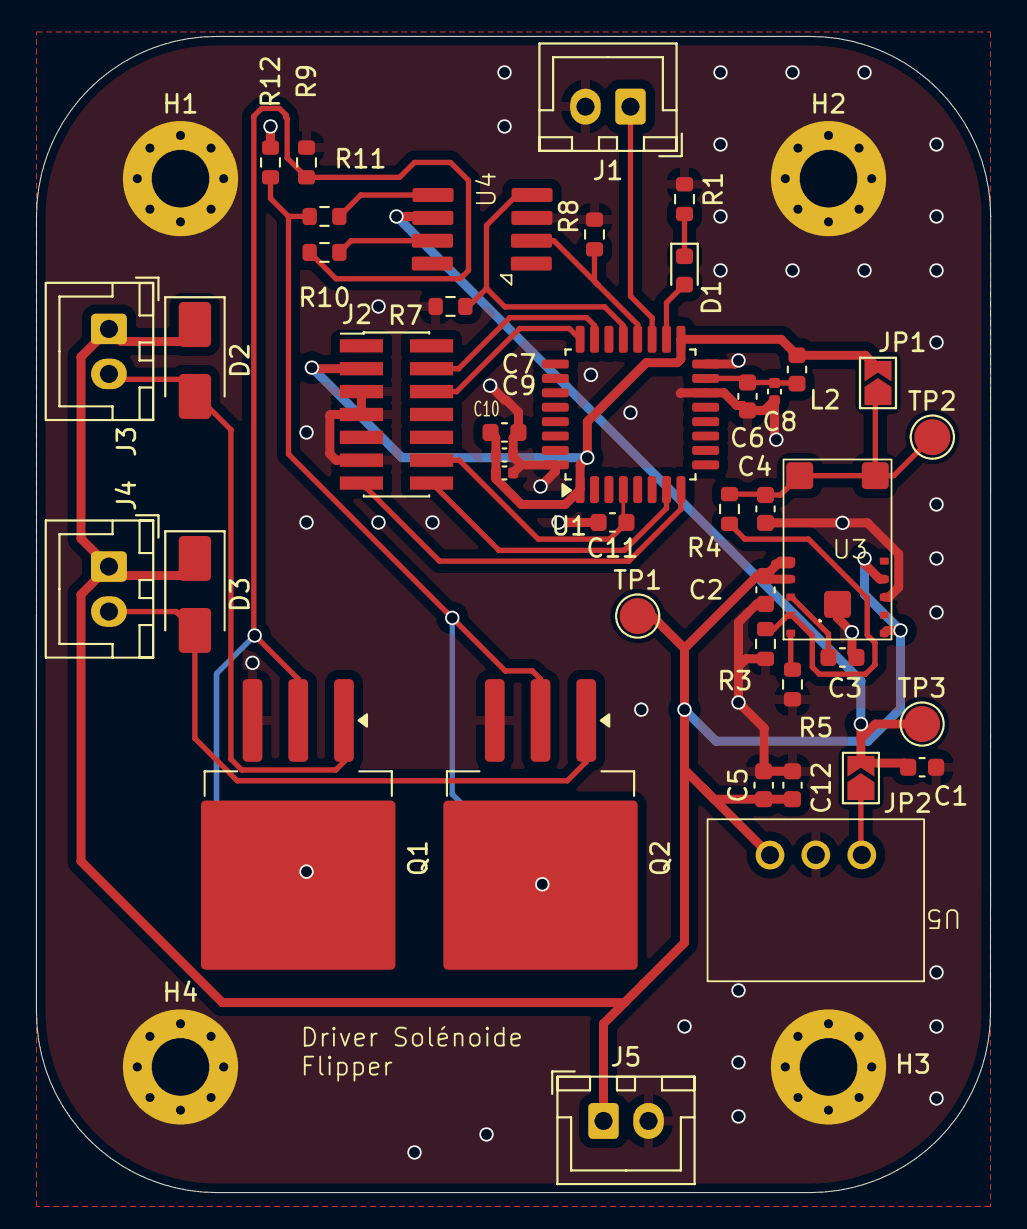
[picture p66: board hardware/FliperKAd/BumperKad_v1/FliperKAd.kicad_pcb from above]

Board: 2 copper layers, 53.0 x 64.2 mm, 46 parts (0 on the bottom side), 26 nets.

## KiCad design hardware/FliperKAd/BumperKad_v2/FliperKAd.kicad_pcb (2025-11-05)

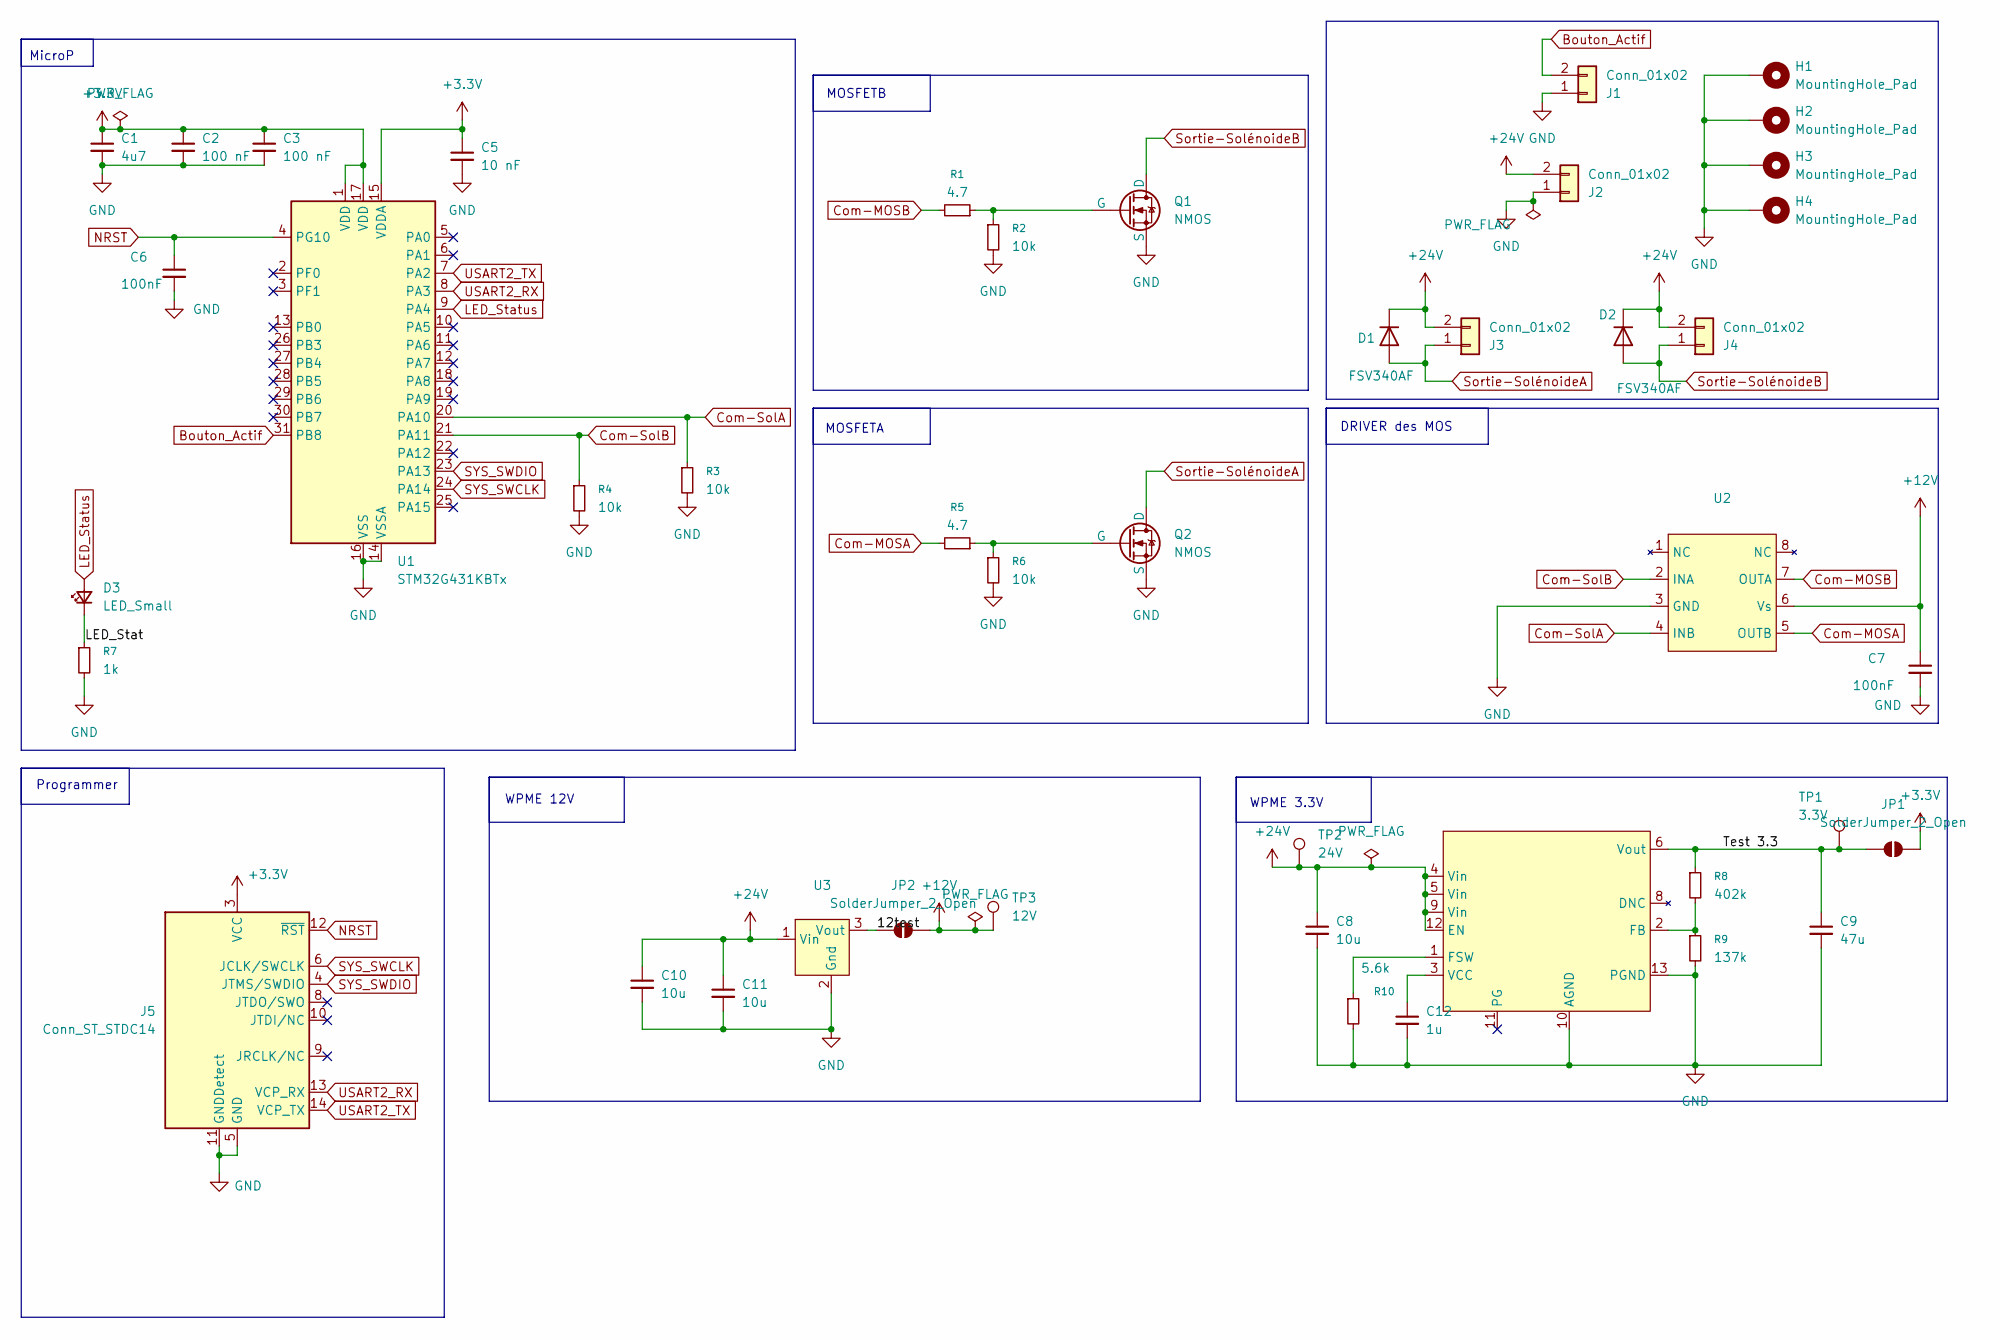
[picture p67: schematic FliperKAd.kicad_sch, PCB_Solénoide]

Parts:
C1: 4u7; C_0603_1608Metric
C2, C3: 100 nF; C_0402_1005Metric
C5: 10 nF; C_0402_1005Metric
C6, C7: 100nF; C_0402_1005Metric
C8, C10, C11: 10u; C_1206_3216Metric
C9: 47u; C_1210_3225Metric
C12: 1u; C_0603_1608Metric
D1, D2: FSV340AF; D_SMA
D3: LED_Small; LED_0603_1608Metric
H1, H2, H3, H4: MountingHole_Pad; MountingHole_3.2mm_M3_Pad_Via
J1, J3, J4: Conn_01x02; JST_XH_B2B-XH-A_1x02_P2.50mm_Vertical
J2: Conn_01x02; AMASS_XT30U-F_1x02_P5.0mm_Vertical
J5: Conn_ST_STDC14; PinHeader_2x07_P1.27mm_Vertical_SMD
JP1, JP2: SolderJumper_2_Open; SolderJumper-2_P1.3mm_Open_TrianglePad1.0x1.5mm
Q1, Q2: NMOS; TO-263-3_TabPin2
R1, R5: 4.7; R_0603_1608Metric
R2, R3, R4, R6: 10k; R_0603_1608Metric
R7: 1k; R_0603_1608Metric
R8: 402k; R_0603_1608Metric
R9: 137k; R_0603_1608Metric
R10: 5.6k; R_0603_1608Metric
TP1: 3.3V; TestPoint_Pad_D2.0mm
TP2: 24V; TestPoint_Pad_D2.0mm
TP3: 12V; TestPoint_Pad_D2.0mm
U1: STM32G431KBTx; LQFP-32_7x7mm_P0.8mm
U2: SOIC-8_5.3x6.2mm_P1.27mm
U3: 173951275
U4: MCP1640x-xMC; WPME_Magic

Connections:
+3.3V: C1.1, C2.1, C3.1, C5.1, J5.3 (VCC), JP1.2 (B), U1.1 (VDD), U1.15 (VDDA), U1.17 (VDD)
+12V: C7.1, JP2.2 (B), TP3.1, U2.6 (Vs)
+24V: C8.1, C10.1, C11.1, D1.1 (K), D2.1 (K), J2.2, J3.2, J4.2, TP2.1, U3.1 (Vin), U4.4 (Vin), U4.5 (Vin), U4.9 (Vin), U4.12 (EN)
/12test: JP2.1 (A), U3.3 (Vout)
/LED_Stat: D3.1 (K), R7.1
/Test 3.3: C9.1, JP1.1 (A), R8.1, TP1.1, U4.6 (Vout), U4.7 (Vout)
Bouton_Actif: J1.2, U1.31 (PB8)
Com-MOSA: R5.2, U2.5 (OUTB)
Com-MOSB: R1.2, U2.7 (OUTA)
Com-SolA: R3.1, U1.20 (PA10), U2.4 (INB)
Com-SolB: R4.1, U1.21 (PA11), U2.2 (INA)
GND: C1.2, C2.2, C3.2, C5.2, C6.2, C7.2, C8.2, C9.2, C10.2, C11.2, C12.2, H1.1, H2.1, H3.1, H4.1, J1.1, J2.1, J5.5 (GND), J5.7 (GND), J5.11 (GNDDetect), Q1.3 (S), Q2.3 (S), R2.2, R3.2, R4.2, R6.2, R7.2, R9.2, R10.2, U1.14 (VSSA), U1.16 (VSS), U1.32 (VSS), U2.3 (GND), U3.2 (Gnd), U4.10 (AGND), U4.13 (PGND)
LED_Status: D3.2 (A), U1.9 (PA4)
NRST: C6.1, J5.12 (~RST), U1.4 (PG10)
unnamed: Q1.2 (G), R1.1, R2.1
unnamed: Q2.2 (G), R5.1, R6.1
unnamed: R8.2, R9.1, U4.2 (FB)
unnamed: R10.1, U4.1 (FSW)
unnamed: C12.1, U4.3 (VCC)
SYS_SWCLK: J5.6 (JCLK/SWCLK), U1.24 (PA14)
SYS_SWDIO: J5.4 (JTMS/SWDIO), U1.23 (PA13)
Sortie-SolénoideA: D1.2 (A), J3.1, Q2.1 (D)
Sortie-SolénoideB: D2.2 (A), J4.1, Q1.1 (D)
USART2_RX: J5.13 (VCP_RX), U1.8 (PA3)
USART2_TX: J5.14 (VCP_TX), U1.7 (PA2)

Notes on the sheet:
MOSFETB
WPME 3.3V
WPME 12V
DRIVER des MOS
MicroP
MOSFETA
Programmer

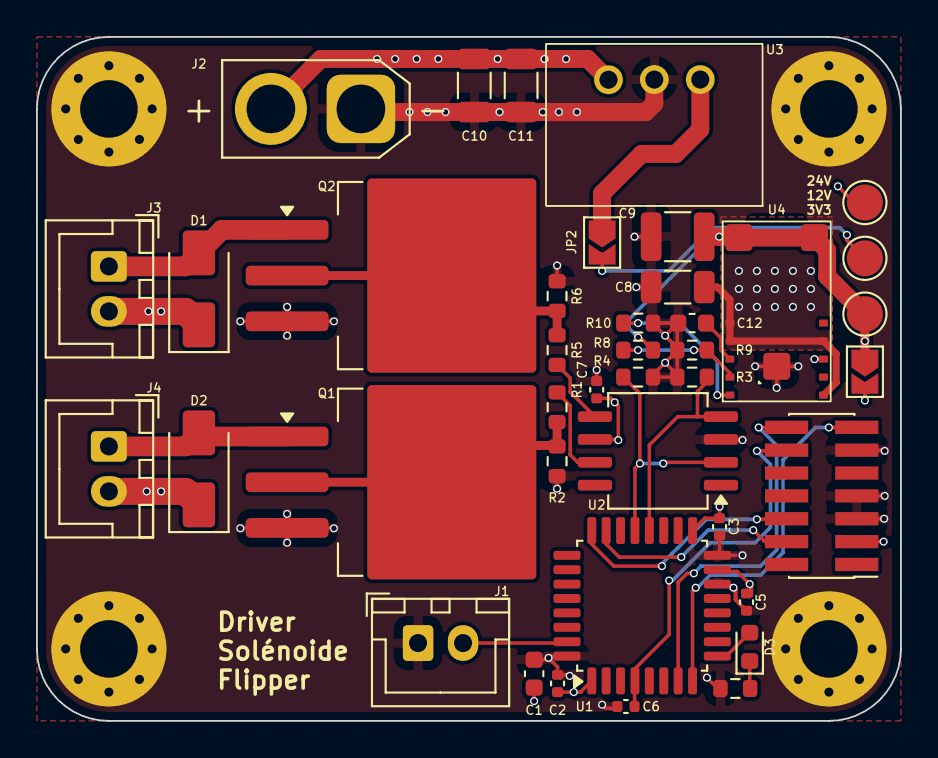
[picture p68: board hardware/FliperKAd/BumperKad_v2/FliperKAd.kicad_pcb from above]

Board: 4 copper layers, 48.0 x 38.0 mm, 44 parts (0 on the bottom side), 25 nets.

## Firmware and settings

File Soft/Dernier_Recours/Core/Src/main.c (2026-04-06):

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
/* Includes ------------------------------------------------------------------*/
#include "main.h"

/* USER CODE BEGIN Includes */
#include <stdio.h>
#include <neopixel.h>

/* USER CODE END Includes */

/* USER CODE BEGIN PD */
#define SPI1_CS_Pin GPIO_PIN_6
#define SPI1_CS_Port GPIOB

uint8_t tx[16] = { 0 };     // dummy bytes to clock the slave
uint8_t rx[16] = { 0 };     // buffer for sensor data
uint16_t sensor[8];		  // nombre de capteurs
int score = 0; // Initialisation du compteur à 0
int deja_compte = 0; // Empêchera un effet rebond "flag"

#define CS_LOW()  HAL_GPIO_WritePin(SPI1_CS_Port, SPI1_CS_Pin, GPIO_PIN_RESET)
#define CS_HIGH() HAL_GPIO_WritePin(SPI1_CS_Port, SPI1_CS_Pin, GPIO_PIN_SET)
/* USER CODE END PD */

SPI_HandleTypeDef hspi1;

TIM_HandleTypeDef htim1;
TIM_HandleTypeDef htim2;
DMA_HandleTypeDef hdma_tim1_ch1;
DMA_HandleTypeDef hdma_tim2_ch1;

UART_HandleTypeDef huart1;
UART_HandleTypeDef huart2;

/* USER CODE BEGIN PV */
#define LED_NUMBER 7

/* USER CODE END PV */

void SystemClock_Config(void);
static void MX_DMA_Init(void);
static void MX_GPIO_Init(void);
static void MX_TIM1_Init(void);
static void MX_SPI1_Init(void);
static void MX_USART1_UART_Init(void);
static void MX_USART2_UART_Init(void);
static void MX_TIM2_Init(void);
/* USER CODE BEGIN 0 */
int __io_putchar(int ch) {
	HAL_UART_Transmit(&huart2, (uint8_t*) &ch, 1, HAL_MAX_DELAY);
	return ch;
}

void read_and_decode_sensors(void) {
    for (int i = 0; i < 8; i++) {
        uint8_t tx_buff[3];
        uint8_t rx_buff[3];

        // Construction de l'octet de commande pour MCP3208
        // Byte 0: Start bit (0x04)
        // Byte 1: Single/Diff + Channel D2, D1, D0
        // Pour MCP3208: Start=1, SGL=1, D2-D0=channel

#define START_BIT 0x04
#define SINGLE_BIT 0x02
#define D2_POS 0x01

        uint8_t d2 = ((i >> 2) & D2_POS);
        tx_buff[0] = START_BIT | SINGLE_BIT | d2; // Start bit + SGL + D2
        tx_buff[1] = (i << 6) & 0xC0;          // D1 + D0 + dummies
        tx_buff[2] = 0x00;                     // Dummy byte

        CS_LOW();
        // On envoie 3 octets pour recevoir la réponse d'un canal
        HAL_SPI_TransmitReceive(&hspi1, tx_buff, rx_buff, 3, 10);
        CS_HIGH();

        // Reconstruction sur 12 bits (les données chevauchent les octets 1 et 2)
        // MCP3208 : Les 4 derniers bits de rx[1] et tout rx[2]
        sensor[i] = ((rx_buff[1] & 0x0F) << 8) | rx_buff[2];

        // Petit délai pour laisser l'ADC respirer (optionnel selon vitesse SPI)
        // for(int k=0; k<100; k++);
    }
}

int print_sensors(void) {
	char buffer[100];
	int len = snprintf(buffer, sizeof(buffer),
			"S: %4d %4d %4d %4d %4d %4d %4d %4d\r\n", sensor[0], sensor[1],
			sensor[2], sensor[3], sensor[4], sensor[5], sensor[6], sensor[7]);
	//HAL_UART_Transmit(&huart2, (uint8_t*) buffer, len, HAL_MAX_DELAY);
	if (sensor[0]<1000 && deja_compte == 0){
		score+=1;
		deja_compte=1; //On bloque le comptage
		len = snprintf(buffer, sizeof(buffer), "Score: %d\n\r", score);
		HAL_UART_Transmit(&huart2, (uint8_t*) buffer, len, HAL_MAX_DELAY);
	}
	if (sensor[0]>1000){
		deja_compte=0; //On réautorise le comptage
	}
	if (sensor[1]<1000 && deja_compte == 0){
		score+=1;
		deja_compte=1; //On bloque le comptage
		len = snprintf(buffer, sizeof(buffer), "Score: %d\n\r", score);
		HAL_UART_Transmit(&huart2, (uint8_t*) buffer, len, HAL_MAX_DELAY);
	}
	if (sensor[1]>1000){
		deja_compte=0; //On réautorise le comptage
	}
	if (sensor[2]<1000 && deja_compte == 0){
		score+=1;
		deja_compte=1; //On bloque le comptage
		len = snprintf(buffer, sizeof(buffer), "Score: %d\n\r", score);
		HAL_UART_Transmit(&huart2, (uint8_t*) buffer, len, HAL_MAX_DELAY);
	}
	if (sensor[2]>1000){
		deja_compte=0; //On réautorise le comptage
	}
	if (sensor[3]<1000 && deja_compte == 0){
		score+=1;
		deja_compte=1; //On bloque le comptage
		len = snprintf(buffer, sizeof(buffer), "Score: %d\n\r", score);
		HAL_UART_Transmit(&huart2, (uint8_t*) buffer, len, HAL_MAX_DELAY);
	}
	if (sensor[3]>1000){
		deja_compte=0; //On réautorise le comptage
	}
	if (sensor[4]<1000 && deja_compte == 0){
		score+=1;
		deja_compte=1; //On bloque le comptage
		len = snprintf(buffer, sizeof(buffer), "Score: %d\n\r", score);
		HAL_UART_Transmit(&huart2, (uint8_t*) buffer, len, HAL_MAX_DELAY);
	}
	if (sensor[4]>1000){
		deja_compte=0; //On réautorise le comptage
	}
	if (sensor[5]<1000 && deja_compte == 0){
		score+=1;
		deja_compte=1; //On bloque le comptage
		len = snprintf(buffer, sizeof(buffer), "Score: %d\n\r", score);
		HAL_UART_Transmit(&huart2, (uint8_t*) buffer, len, HAL_MAX_DELAY);
	}
	if (sensor[5]>1000){
		deja_compte=0; //On réautorise le comptage
	}
	if (sensor[6]<1000 && deja_compte == 0){
		score+=1;
		deja_compte=1; //On bloque le comptage
		len = snprintf(buffer, sizeof(buffer), "Score: %d\n\r", score);
		HAL_UART_Transmit(&huart2, (uint8_t*) buffer, len, HAL_MAX_DELAY);
	}
	if (sensor[6]>1000){
		deja_compte=0; //On réautorise le comptage
	}
	if (sensor[7]<1000 && deja_compte == 0){
		score+=1;
		deja_compte=1; //On bloque le comptage
		len = snprintf(buffer, sizeof(buffer), "Score: %d\n\r", score);
		HAL_UART_Transmit(&huart2, (uint8_t*) buffer, len, HAL_MAX_DELAY);
	}
	if (sensor[7]>1000){
		deja_compte=0; //On réautorise le comptage
	}
	return score;
}
/* USER CODE END 0 */

/**
  * @brief  The application entry point.
  * @retval int
  */
int main(void)
{

  /* MCU Configuration--------------------------------------------------------*/

  /* Reset of all peripherals, Initializes the Flash interface and the Systick. */
  HAL_Init();

  /* Configure the system clock */
  SystemClock_Config();

  /* Initialize all configured peripherals */
  MX_DMA_Init();
  MX_GPIO_Init();
  MX_TIM1_Init();
  MX_SPI1_Init();
  MX_USART1_UART_Init();
  MX_USART2_UART_Init();
  MX_TIM2_Init();
  /* USER CODE BEGIN 2 */
  //CS_HIGH();

  HAL_TIM_Base_Start(&htim1);


  int red = 255;
  int green = 255;
  int blue = 255;
  const uint8_t digits[10][7]={{1,1,0,1,1,1,1},{0,0,0,1,0,0,1},
		  	  	  	  	  	{1,0,1,0,1,1,1},{1,0,1,1,1,0,1},
							{0,1,1,1,0,0,1},{1,1,1,1,1,0,0},
							{1,1,1,1,1,1,0},{1,0,1,1,0,0,1},
							{1,1,1,1,1,1,1},{1,1,1,1,1,0,1}};
  led_render();
  int result = 0;
  /* USER CODE END 2 */

  /* Infinite loop */
  /* USER CODE BEGIN WHILE */
  printf("Hello World \n\r");
  while (1)
  {
		read_and_decode_sensors();
		result += print_sensors();

		if (HAL_GPIO_ReadPin(Sol_In_GPIO_Port,Sol_In_Pin)){
				result+=1;
				HAL_Delay(50);
				printf("ding \n\r");
			}

		if (result>=10){
			  		  result=0;
			  	  }
			  	//for (int j=0; j < 6; j++){
		//printf("%d \n\r",result);
		for (int i = 0; i < LED_NUMBER; i++) {
	        if(digits[result][i]==1) {
	        	led_set_RGB(i,255,255,255);
	        }
	        else {
            led_set_RGB(i, 0, 0 , 0);
	        }
				    //}
		}
		led_render();
		HAL_Delay(10); //besoin ajustement (balle à 6m/s sur 3,4mm)
    /* USER CODE END WHILE */

    /* USER CODE BEGIN 3 */
  }
  /* USER CODE END 3 */
}

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


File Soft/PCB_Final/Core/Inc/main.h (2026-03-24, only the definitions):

#define Bouton_Droit_Pin GPIO_PIN_1
#define Bouton_Droit_GPIO_Port GPIOA
#define LED_Status_Pin GPIO_PIN_4
#define LED_Status_GPIO_Port GPIOA
#define Com_Sol_A_Pin GPIO_PIN_5
#define Com_Sol_A_GPIO_Port GPIOA
#define Com_Sol_B_Pin GPIO_PIN_6
#define Com_Sol_B_GPIO_Port GPIOA
#define Com_Sol_C_Pin GPIO_PIN_7
#define Com_Sol_C_GPIO_Port GPIOA
#define Com_Sol_D_Pin GPIO_PIN_0
#define Com_Sol_D_GPIO_Port GPIOB
#define Com_Sol_E_Pin GPIO_PIN_8
#define Com_Sol_E_GPIO_Port GPIOA
#define Com_Sol_F_Pin GPIO_PIN_9
#define Com_Sol_F_GPIO_Port GPIOA
#define Com_Sol_G_Pin GPIO_PIN_10
#define Com_Sol_G_GPIO_Port GPIOA
#define Com_Sol_H_Pin GPIO_PIN_11
#define Com_Sol_H_GPIO_Port GPIOA
#define USR_Btn_Pin GPIO_PIN_12
#define USR_Btn_GPIO_Port GPIOA
#define CS_Pin GPIO_PIN_15
#define CS_GPIO_Port GPIOA
#define Bouton_Gauche_Pin GPIO_PIN_6
#define Bouton_Gauche_GPIO_Port GPIOB
#define BOOT_0_Pin GPIO_PIN_8
#define BOOT_0_GPIO_Port GPIOB

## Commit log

2025-09-23 ajout du PCB
    [FliperKAd.kicad_pcb, FliperKAd.kicad_sch]
2025-09-23 ajout du buck
    [FliperKAd.kicad_sch]
2025-09-30 Avancement du PCB
    [FliperKAd.kicad_sch]
2025-09-30 Fin de séance du 30
    [FliperKAd.kicad_sch]
2025-10-07 Ajout du dossier Doc
    [FliperKAd.kicad_sch]
2025-10-07 Finalisation schematics + empreintes
    [FliperKAd.kicad_sch]
2025-10-07 je me suis rendu compte qu'il me manque un transistor, oups
    [FliperKAd.kicad_pcb]
2025-10-20 PCB Routé
    [FliperKAd.kicad_pcb, FliperKAd.kicad_sch]
2025-10-20 Manque un truc
    [FliperKAd.kicad_sch]
2025-10-21 Create Bilan oral 2 with project notes
    Added notes for PCB design and coilgun specifications.
2025-10-21 Add purchasing link for copper wire
    Added a link for purchasing copper wire.
2025-10-22 just in time
    [FliperKAd.kicad_pcb, FliperKAd.kicad_sch]
2025-11-05 pcb fini plus routage à valider et commander
    [FliperKAd.kicad_pcb, FliperKAd.kicad_sch]
2025-11-05 dernière vérif avec Mr PPZ
    [FliperKAd-B_Cu.gbr, FliperKAd-B_Mask.gbr, FliperKAd-B_Paste.gbr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]
2025-11-05 review pcb, make v2
    [FliperKAd-B_Cu.gbr, FliperKAd-B_Mask.gbr, FliperKAd-B_Paste.gbr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]
2025-11-18 Software+img appel de courant
2025-11-18 enorme faute de frappe
2026-01-13 réorga
    [FliperKAd-B_Cu.gbr, FliperKAd-B_Mask.gbr, FliperKAd-B_Paste.gbr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]
2026-01-13 suppression duplicata
    [FliperKAd-B_Cu.gbr, FliperKAd-B_Mask.gbr, FliperKAd-B_Paste.gbr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]
2026-01-13 Enhance README with bumper and solenoid details
    Added images and detailed descriptions for bumpers and solenoids in the README.
2026-01-13 Update README with launcher and chassis details
    Corrected formatting and added sections for the launcher and chassis.
2026-01-13 Update README with PCB assembly issues
    Clarify issues encountered during PCB assembly and testing.
2026-01-13 Fix typos and clarify PCB problems in README
    Corrected typos and clarified PCB issues in README.
2026-01-13 Update README with score counter and chassis information
    Added details about the score counter and chassis design.
2026-01-13 Update README with bumper support image
    Added image of printed bumper support and updated text.
2026-03-16 update pcb
    [Driver2Sol.kicad_sch, PCB_Final.kicad_pcb, PCB_Final.kicad_sch]
2026-03-16 reset PCB final
    [Driver2Sol.kicad_sch, PCB_Final.kicad_pcb, PCB_Final.kicad_sch]
2026-03-31 Update README with sensors information
    Added section about sensors and their functionality.
2026-04-06 pour le compte rendu
    [PCB_Final.kicad_pcb, PCB_Final.kicad_sch]
2026-04-06 petit oubli'
    [PCB_Final.kicad_pcb]
2026-04-07 Update README with corrections and new sections
    Corrected spelling of 'schéma' and added sections about the game table and chassis.
2026-04-07 Remove photodiode image from README
    Removed the image of the PCB with photodiodes from the README.

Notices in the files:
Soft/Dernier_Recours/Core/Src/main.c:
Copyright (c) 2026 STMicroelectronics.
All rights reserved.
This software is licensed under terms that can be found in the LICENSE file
